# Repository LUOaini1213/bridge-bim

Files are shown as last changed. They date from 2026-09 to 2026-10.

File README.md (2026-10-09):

# bridge-bim · 曲线 T 梁桥 BIM



**A curved precast-T-girder highway bridge modelled from its alignment up, in Rhino 8 and IFC 4.3, with a
construction-stage structural analysis written back into the model.**
A 1110 m route (tangent – clothoid – circular arc – clothoid – tangent, with a parabolic crest curve and
superelevation) carries a 12-span, 3-unit continuous bridge: 1470 elements, 120 of them precast T-girders.
Girder lengths are equalised as an interval-stabbing problem — 10 lengths instead of 66, with an optimality
certificate. The superstructure is analysed stage by stage (simply supported girders, then continuity) under
dead load and the JTG D60-2015 lane load, by a standard-library stiffness solver that is cross-checked against
OpenSees. The results size the bearings — for pressure, and for the shear, rotation and slip that temperature,
shrinkage, creep and braking impose on them, which puts PTFE sliding bearings at the expansion ends — and go
back into the Rhino objects and into two IFC structural analysis models. It is a teaching-level analysis — no
prestressing, reinforcement or section-capacity design.
32 design, construction and structural checks all pass, and each is proven to fail on a deliberately
broken model. The precast yard and the erector are scheduled together in 4D and exported with the model
to IFC 4.3 (IfcAlignment + IfcBridge + IfcWorkSchedule + IfcStructuralAnalysisModel), schema-valid and
byte-reproducible. CI re-derives every number in this README from the committed `.3dm`, IFC and CSV files.

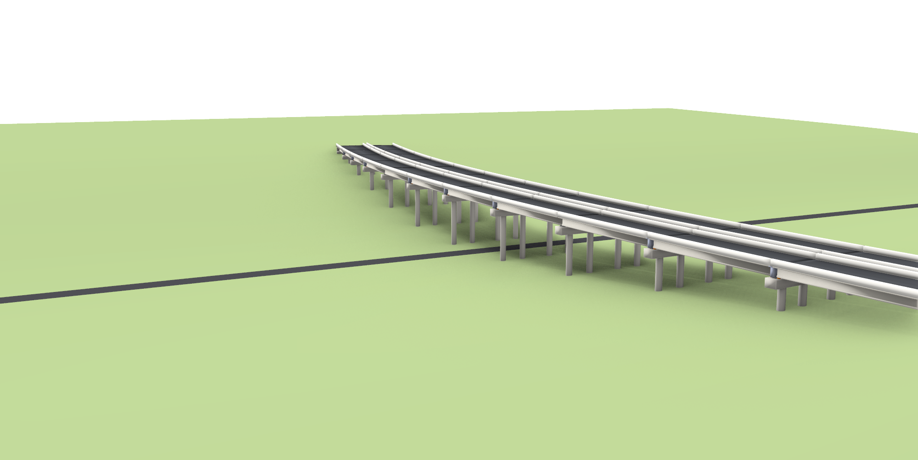
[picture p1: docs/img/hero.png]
Rhino 8 渲染：曲线 T 梁桥与被交道路


## 一眼看懂

- 路线 **1110** m：直线 – 回旋线 – 圆曲线 R=**700** m – 回旋线 – 直线，竖曲线 R=**10000** m，圆曲线段超高 **4%**
- 桥梁 **K10+350.000 – K10+710.000**，**12**×30 m 分 **3** 联、先简支后连续，左右两幅；共 **1470** 个构件，其中预制 T 梁 **120** 片
- 预制梁长：逐片按名义缝宽下料要 **66** 种长度，归并后 **10** 种（中跨 **4** + 边跨 **6**），并给出「不可能更少」的证书
- 上部结构计算：一期恒载由简支的预制梁承担，体系转换后二期恒载与公路-I级车道荷载由连续梁承担；
  30 条梁位线里基本组合正弯矩最大 **10023.1** kN·m、墩顶负弯矩最大 **-6731.5** kN·m，活载长期挠度最大为限值的 **0.238**；
  支座按压应力选平面（伸缩端 φ450、连续墩 500×600），利用率最大 **0.833**；自写求解器与 OpenSees 互核到 1e-9
- 支座位移：伸缩端离一联的不动点最远 **60.62** m，温度、收缩、徐变要缩短 **48.8** mm，普通板式支座最厚一档也不够，
  改用四氟滑板支座；连续墩的普通板式支座剪切变形利用率 **0.822**。横向分布按教材更严的窄桥判别 θ' = **0.408** > 0.3，
  另用 G-M 法算一遍取大值
- 检查：模型 17 条 + 梁场与架梁 5 条 + 上部结构 10 条，**32/32** 通过；每条都有一个故意弄坏的反例，证明它会变红
- 4D 原基线：梁场 **16** 个台座提前 **21** 天开工，架桥机 **50** 天架完 120 片、**0** 天等梁；存梁峰值 **34** 片（容量 **40**）；**2027-02-02** 完成全部体系转换。新增完整示例计划含后续工序，默认转换与收尾日期见下文
- IFC 4.3：**111,481** 个实体，schema 校验 **0** 个问题；几何引擎逐件算出实体，体积与位置和模型一致到 1e-6
- 下文每个数字都由 `scripts/check_readme.py` 对着已提交的产物回算，CI 每次提交都跑

路线、地形、桥梁都是虚构的示例；尺寸、工效、设备能力这些不是物理常数的参数集中在
[`bridge/config.py`](bridge/config.py)，逐项标着【几何】或【假设】。改那里、重跑，下面的表全部跟着变。

## 一个模型，多份产物

```mermaid
flowchart LR
  cfg["bridge/config.py<br/>路线 · 桥型 · 工效参数 · 规范系数"] --> core["bridge/<br/>路线 · 构件 · 检查 · 梁长归并 · 排程 · 结构计算"]
  core --> rh["Rhino 8<br/>rhino/build_model.py"]
  rh --> m3["model/bridge_bim.3dm<br/>构件 + BIM 属性 + 内力"]
  rh --> img["docs/img/*.png<br/>渲染 · 4D · 图纸 · 弯矩包络"]
  core --> ifc["model/bridge_bim.ifc<br/>IFC 4.3 + 结构分析模型"]
  core --> csv["data/*.csv<br/>梁长 · 垫石标高 · 工程量 · 排程 · 内力 · 支座反力"]
  m3 -. rhino3dm 读回 .-> ci["tests/ + CI"]
  ifc -. ifcopenshell 读回 + 几何引擎 .-> ci
  csv -. 重算比对 .-> ci
```

构件几何只算一次（[`bridge/model.py`](bridge/model.py)），Rhino 脚本和 IFC 导出读的是同一份顶点与参数；
`.3dm` 由 rhino3dm 读回、IFC 由 ifcopenshell 的几何引擎重新算成实体，各自和模型逐件对照。
IFC 不从 `.3dm` 反读，因为路线的语义定义（线元类型、半径、回旋线参数、竖曲线）在 Rhino 的网格里已经不存在了。

## 路线：平、纵、横

| 线元 | 起点桩号 | 长度 (m) | 曲率 |
|---|---|---|---|
| 直线 | K10+000.000 | 320 | 0 |
| 回旋线 | K10+320.000 | 110 | 0 → 1/700 |
| 圆曲线 | K10+430.000 | 190 | 1/700 |
| 回旋线 | K10+620.000 | 110 | 1/700 → 0 |
| 直线 | K10+730.000 | 380 | 0 |

回旋线没有解析解：平面坐标用分段 5 点 Gauss–Legendre 积分方位角得到，再拿测量上的级数公式
（x = l − l⁵/40A⁴ + …，y = l³/6A² − …）独立算一遍，两者差 < 1e-9 m；导出的 IfcGradientCurve 交给
ifcopenshell 的几何内核求值，是第三种算法，与自己的积分在平面上差 < 1e-5 m、高程上差 < 1e-6 m。

纵断面：变坡点 K10+520.000，高程 136.320，前坡 +1.600%、后坡 -1.200%，抛物线竖曲线 L=280 m
（R=10000，T=140，E=0.980）。横坡：直线段各幅 2% 向外侧排水，圆曲线段两幅都 4% 超高向曲线内侧，
在回旋线上线性过渡；每幅绕自己的中心线旋转。

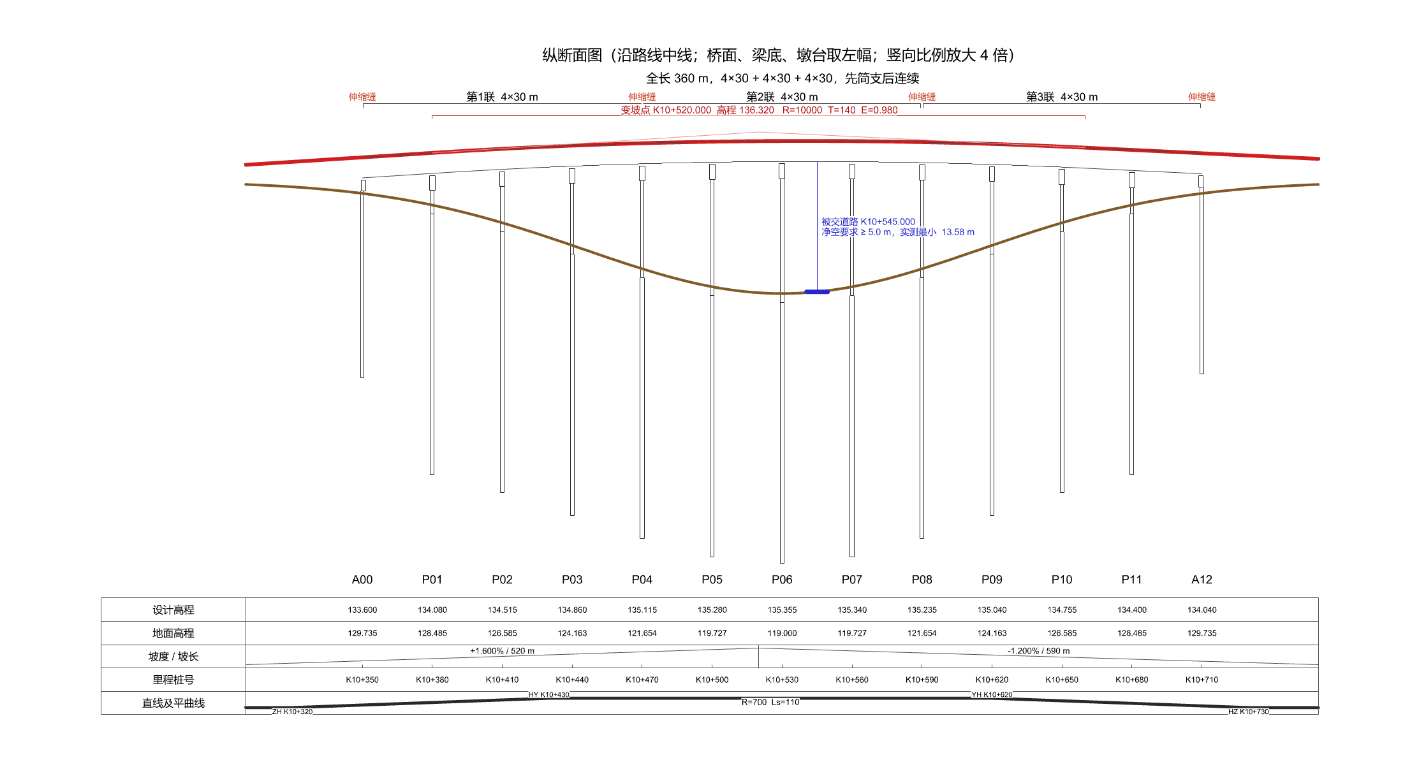
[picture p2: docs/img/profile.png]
纵断面图：地面线、设计线、墩台、竖曲线要素与资料表


## 结构体系：先简支后连续

12 跨分 3 联（4×30 + 4×30 + 4×30）。13 条支承线分三种：2 个桥台、2 个过渡墩（两联交界，设伸缩缝）、
9 个连续墩。

- **伸缩端**（桥台、过渡墩）：梁端面距支承线 0.04 m，联与联之间留 0.08 m 伸缩缝；梁直接落在四氟滑板支座 GYZF4 φ450×87 上，共 60 个。
- **连续端**（连续墩）：架梁时两跨梁端各落在一个临时支座上，共 180 个；墩中心一排 GJZ 500×600×90 矩形板式支座（90 个，
  顺桥向 500 mm）整个落在两梁端之间的缝下，体系转换前不接触预制梁。浇墩顶现浇连续段、张拉负弯矩钢束后拆临时支座，
  由永久支座受力。连续段宽 0.708–0.998 m，由梁长归并决定（见下节）。支座规格由压应力、剪切变形、转角与抗滑验算定
  （见「上部结构计算」）。
- 梁端面平行于径向支承线（曲线上最大斜角 1.228°），所以同一条缝在梁宽范围内等宽；
  盖梁、台帽顶面按该处桥面横坡做成斜面，垫石高 0.150–0.156 m。
- 每跨相邻两片梁之间 5 道横隔板（两道端横隔板 + 1/4、1/2、3/4 跨），沿径向、腹板面到腹板面：
  这是荷载横向分布用修正偏心压力法的前提（桥上有可靠的横向联结）。

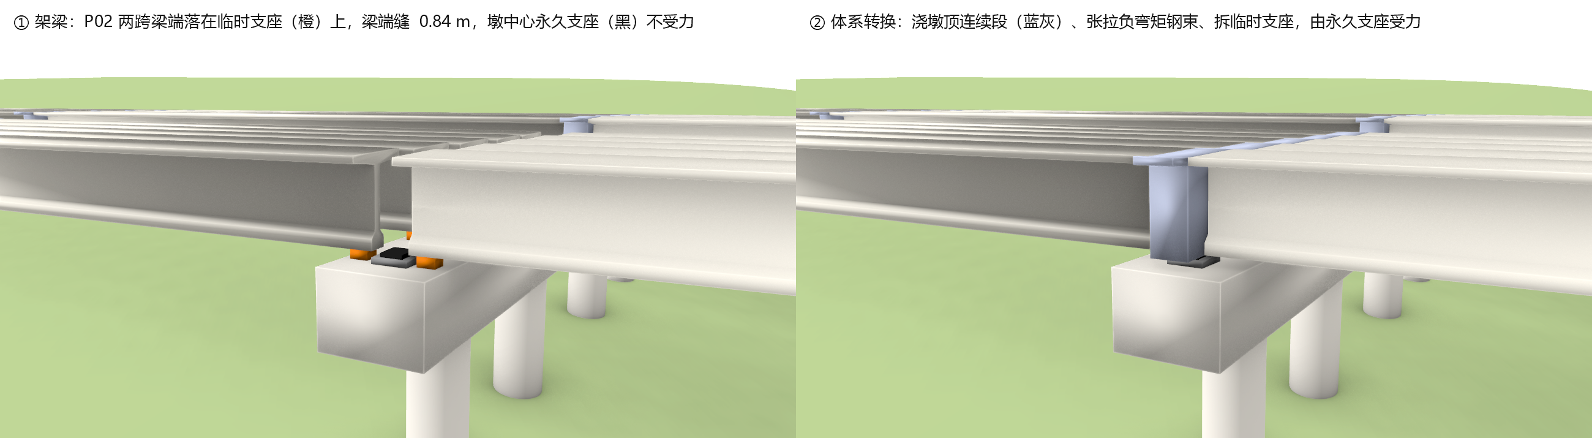
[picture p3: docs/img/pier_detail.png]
连续墩近景：① 架梁阶段落在临时支座上 ② 体系转换后由永久支座受力


## 梁长归并：66 种 → 10 种

直梁放在曲线上：每片梁搁在两条径向支承线之间、同一偏距处两点连成的三维弦上，曲线外侧的弦比内侧长，
左右两幅、每跨、每个梁位都不一样。逐片按名义缝宽（伸缩端 0.04 m、连续端 0.425 m）下料取整到 10 mm，
要 **66** 种梁长——66 种端模设置。

但连续端的缝宽可以在 0.35–0.50 m 之间浮动（连续段宽 0.70–1.00 m），伸缩端不动。于是每片梁的可行长度是
一个区间，问题变成「用最少的长度刺穿全部区间」。这是区间刺穿：按右端点排序，遇到还没被刺穿的区间就在它的
右端点放一个点——贪心的结果可证最优。程序同时输出**证书**：一组两两不相交的区间，个数等于所选长度数，
任何方案都至少要这么多种。中跨梁（两端连续）与边跨梁（一端伸缩）的端部构造不同，分开归并：

| 梁型 | 长度 (m) | 片数 |
|---|---|---|
| 中跨 | 28.78 | 16 |
| 中跨 | 29.09 | 20 |
| 中跨 | 29.41 | 20 |
| 中跨 | 29.74 | 4 |
| 边跨 | 29.09 | 8 |
| 边跨 | 29.30 | 11 |
| 边跨 | 29.48 | 11 |
| 边跨 | 29.63 | 13 |
| 边跨 | 29.80 | 9 |
| 边跨 | 30.01 | 8 |

允许的缝宽浮动越大，需要的长度越少——这是现浇工作量与预制规格之间的取舍：

| 连续端浮动 | 连续段宽 (m) | 中跨 | 边跨 | 合计 |
|---|---|---|---|---|
| ±0.005 | 0.84–0.86 | 34 | 26 | 60 |
| ±0.020 | 0.81–0.89 | 10 | 16 | 26 |
| ±0.040 | 0.77–0.93 | 6 | 11 | 17 |
| ±0.060 | 0.73–0.97 | 4 | 7 | 11 |
| ±0.075 | 0.70–1.00 | 4 | 6 | 10 |
| ±0.100 | 0.65–1.05 | 3 | 5 | 8 |
| ±0.125 | 0.60–1.10 | 2 | 4 | 6 |
| ±0.150 | 0.55–1.15 | 2 | 4 | 6 |

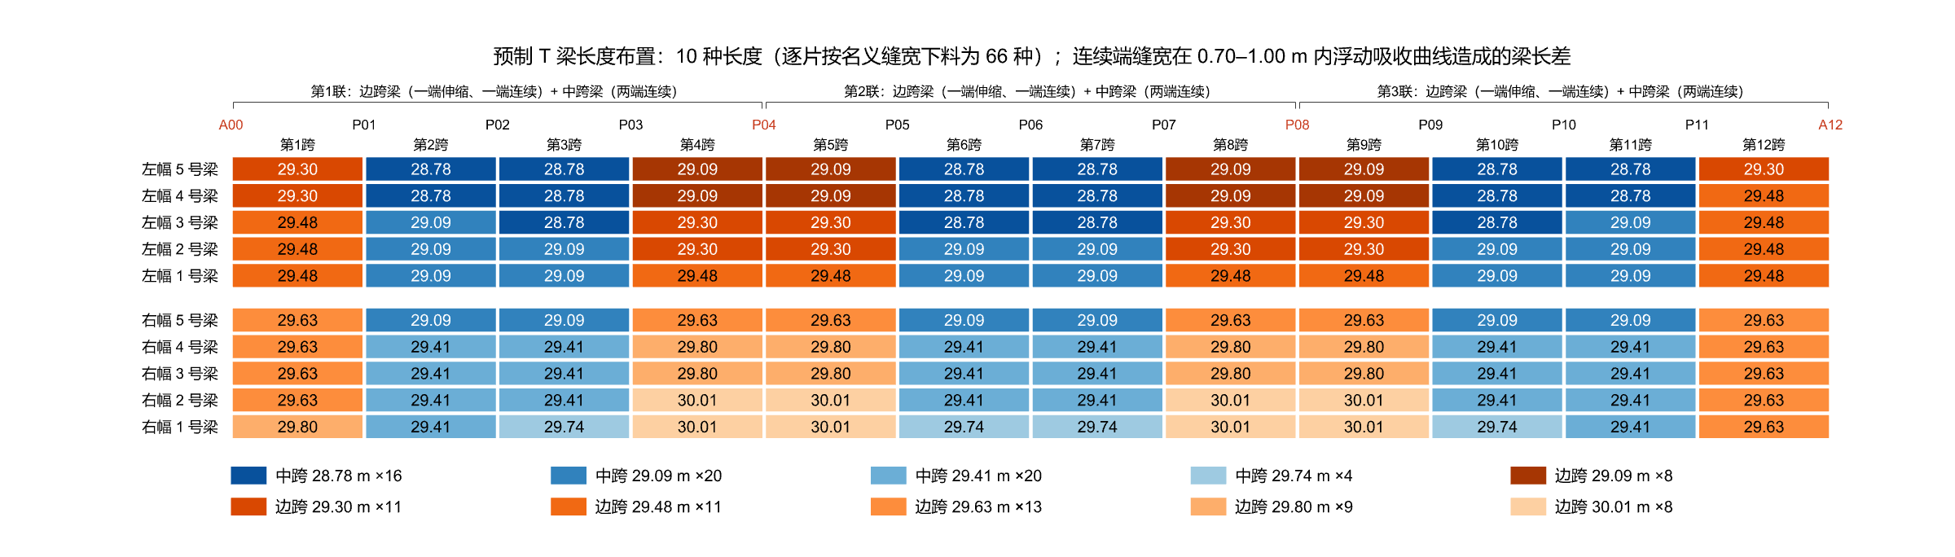
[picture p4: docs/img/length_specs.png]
预制 T 梁长度布置：10 种长度


## 构件与检查

| 类别 | 数量 |
|---|---|
| 预制 T 梁 | 120 |
| 横隔板 | 480 |
| 湿接缝 | 96 |
| 翼缘现浇段 | 48 |
| 墩顶现浇连续段 | 18 |
| 桥面铺装 | 24 |
| 混凝土护栏 | 48 |
| 伸缩装置 | 8 |
| 支座垫石 | 150 |
| 板式橡胶支座 | 150 |
| 临时支座 | 180 |
| 盖梁 | 22 |
| 桥台台帽 | 4 |
| 桥台背墙 | 4 |
| 墩柱 | 44 |
| 系梁 | 22 |
| 钻孔灌注桩 | 52 |

铺装、护栏、翼缘现浇段沿路线每 1.5 m 取样，外缘跟随曲线（直梁「以直代曲」，曲线由现浇部分吸收）；
每个多面体都闭合、法向朝外，共 1382 个实体。检查直接在生成出的几何上量，不信任「按构造应当成立」：

| 检查 | 结果 | 实测 |
|---|---|---|
| 平曲线线元衔接：位置、方位角、曲率连续 | ✅ | 4 处衔接，最大位置差 < 1e-09 m，方位角差 < 1e-09 rad，曲率差 < 1e-12 |
| 竖曲线起终点：高程与纵坡连续 | ✅ | 2 处，最大高程差 < 1e-09 m，坡度差 < 1e-09 |
| 跨径 = 30 m（沿中线逐跨量） | ✅ | 12 跨，最大偏差 < 1e-09 m |
| 伸缩端梁端距支承线 = 0.04 m（端面与支承线平行） | ✅ | 60 个梁端 × 12 个端面顶点，最大偏差 < 1e-09 m |
| 连续墩现浇连续段宽 0.70 – 1.00 m | ✅ | 90 处，0.708 – 0.998 m，梁端面不平行度 < 1e-09 m |
| 湿接缝宽 ≥ 0.45 m（翼缘边缘实测） | ✅ | 量了 192 处，0.600 – 0.623 m |
| 支座垫石高 0.15 – 0.40 m | ✅ | 150 个垫石，0.150 m（S-L01-5a）– 0.156 m（S-L05-5a） |
| 垫石、临时支座落在盖梁 / 台帽顶面内 | ✅ | 最小边距 0.150 m（TS-R01-2b） |
| 临时支座高 ≥ 0.10 m | ✅ | 180 个，0.226 m（TS-R01-2b）– 0.254 m（TS-R02-1a） |
| 临时支座与永久支座垫石平面净距 ≥ 0.05 m | ✅ | 最小 0.100 m（TS-R10-1a） |
| 连续墩永久支座全在现浇连续段下（距预制梁端 ≥ 0.05 m） | ✅ | 最小 0.100 m（B-P09-R1） |
| 墩盖梁底高出地面（桥台埋入路堤，不在此列） | ✅ | 最小 1.30 m（CAP-P01-L） |
| 被交道路净空 ≥ 5.0 m | ✅ | 最小 13.58 m（G-L07-5 梁底） |
| 墩柱外缘距被交道路边线 ≥ 1.0 m | ✅ | 最小 9.54 m（C-P06-L2） |
| 最重预制梁 ≤ 架桥机额定 120 t | ✅ | G-R08-1 65.2 t，利用率 54% |
| 多面体闭合、法向朝外 | ✅ | 1382 个实体，不合格 0 个 |
| 预制梁长规格数达到下界（区间刺穿最优性证书） | ✅ | 中跨 4 种、边跨 6 种；实际梁长与规格最大差 < 1e-09 m，越出可行区间 0 片 |
| 存梁峰值 ≤ 存梁容量（20 个台座 × 2 层） | ✅ | 容量 40 片，峰值 34 片（2027-01-02） |
| 存梁期 ≤ 90 天 | ✅ | 最长 15 天 |
| 架设时龄期 ≥ 14 天 | ✅ | 最短 18 天 |
| 龙门吊抬吊能力 ≥ 最重预制梁 | ✅ | 2 台 × 50 t × 0.8 = 80 t，最重梁 65.2 t |
| 梁场不占路基（距路线中线 ≥ 25 m） | ✅ | 梁场边缘距中线 38.0 m |

「全过」本身不是证据。[`tests/test_model.py`](tests/test_model.py) 给每条检查配了一个反例：把一片梁的
伸缩端挪 1 cm、把连续端往墩中心线伸 0.2 m、把永久支座往梁端下推 0.1 m、翻转一个面、把一片梁多切 5 cm……
每改一处，对应那一条必须变红。

## 支座垫石标高表

每个永久支座的平面坐标、支座顶、垫石顶、盖梁顶高程与垫石高，全表 150 行见
[`data/bearings.csv`](data/bearings.csv)；临时支座 180 行见 [`data/temp_supports.csv`](data/temp_supports.csv)。节选：

| 支座 | 类型 | 规格 | 墩台 | X | Y | 支座顶 | 垫石顶 | 盖梁顶 | 垫石高 |
|---|---|---|---|---|---|---|---|---|---|
| B-L01-1a | 伸缩端 | GYZF4 φ450×87 | A00 | 302.3540 | 177.0626 | 131.5313 | 131.4443 | 131.2937 | 0.1507 |
| B-L01-2a | 伸缩端 | GYZF4 φ450×87 | A00 | 301.1167 | 179.1772 | 131.4688 | 131.3818 | 131.2313 | 0.1505 |
| B-P01-L1 | 连续墩 | GJZ 500×600×90 | P01 | 327.7582 | 192.2012 | 132.0311 | 131.9411 | 131.7911 | 0.1500 |

## 工程量

| 构件 | 数量 | 混凝土 (m³) | 强度等级 | 钢筋 (t) |
|---|---|---|---|---|
| 预制 T 梁 | 120 | 2943.55 | C50 | 559.27 |
| 横隔板 | 480 | 303.21 | C50 | 45.48 |
| 湿接缝 | 96 | 270.56 | C50 | 48.70 |
| 翼缘现浇段 | 48 | 124.22 | C50 | 22.36 |
| 墩顶现浇连续段 | 18 | 353.65 | C50 | 77.80 |
| 桥面铺装 | 24 | 1690.58 | C40+沥青 | 0.00 |
| 混凝土护栏 | 48 | 935.37 | C30 | 102.89 |
| 支座垫石 | 150 | 13.11 | C50 | 1.31 |
| 盖梁 | 22 | 1030.66 | C40 | 164.90 |
| 桥台台帽 | 4 | 111.26 | C40 | 16.69 |
| 桥台背墙 | 4 | 59.35 | C30 | 7.12 |
| 墩柱 | 44 | 638.32 | C40 | 89.37 |
| 系梁 | 22 | 113.52 | C30 | 13.62 |
| 钻孔灌注桩 | 52 | 3079.14 | C30 | 292.52 |
| 结构混凝土合计（不含铺装） | 1108 | 9975.91 |  | 1442.04 |

混凝土量是每个实体的精确体积（散度定理，对 IFC 几何引擎算出的体积核过）；钢筋按各类构件的
kg/m³ 指标估算【假设】，不是配筋计算的结果。

## 上部结构计算（教学级）

[`bridge/structure.py`](bridge/structure.py) 在同一份构件上算上部结构：截面、荷载、支座位置都从 BIM 构件取，
结果写回 `.3dm` 的构件属性和 IFC 的结构分析模型。只用标准库——平面梁单元直接刚度法、带状 Cholesky 分解、
子空间迭代求频率都是自己写的——所以 Rhino 8 里的 Python 3.9 也能直接跑；测试里再用 OpenSees 逐项互核。
这是教学级的内力估算，不是设计：没有预应力钢束，不验算截面应力与承载力，不计收缩徐变与温度梯度引起的内力
（收缩、徐变与温度只用来算支座位移，见下文）。每个规范系数的出处写在 [`bridge/config.py`](bridge/config.py)，没核到原文的标【假设】。

施工阶段（先简支后连续）：

1. **一期恒载**（预制梁 + 横隔板 + 湿接缝 + 翼缘现浇段，构件体积 × 26 kN/m³）由每片预制梁承担：它两端落在永久支座
   （伸缩端）或临时支座（连续端）上，是简支梁。横隔板作为集中力放在它与梁轴的交点，每道一半给两侧的梁。
2. **体系转换**：浇墩顶连续段（混凝土直接浇在永久支座上【假设】）、拆除临时支座——等于把临时支座在阶段一的反力
   反向加到以永久支座为支承的整联连续梁上。
3. **二期恒载**（铺装 + 护栏，每跨五片梁均分）与**汽车荷载**作用在连续梁上。

全桥一期恒载 94680 kN、二期 65739 kN、连续段 9195 kN；每条梁位线每个阶段的支座反力与荷载平衡，
荷载合计与构件体积 × 容重对账，差都 < 1e-9。

汽车荷载按公路-I级车道荷载：qk = 10.5 kN/m，Pk = 2(L0 + 130) = 318.98–321.01 kN（取该联最大计算跨径【假设】）。
逐节点求影响线，均布荷载布满同号区段、集中荷载放在最大竖标处，剪力与支座反力的 Pk 乘 1.2。
荷载横向分布：跨中用修正偏心压力法，支点用杠杆原理法，1–3 列车逐一枚举并乘横向车道布载系数；弯矩全跨用 mc，
剪力与反力的 m 从支点的 m0 线性过渡到 1/4 跨的 mc。连续梁阶段按教材的「等代简支梁」：按跨中挠度相等求抗弯刚度修正系数
C_w = w简支 / w连续，用本仓的梁单元直接算——两跨等跨 1.391、三跨等跨 1.429 / 1.818，与教材表 2-6-4 一致；本桥最大 1.909
（中跨），以 C_w·I 代入后抗扭修正系数 β 由 0.9310 变为 0.9626（抗扭惯性矩不修正），全桥统一取这个偏安全的值。

窄桥判别：教材同一节还说，连续梁按 θ' = (B/2l)·⁴√(C_w·Jx/Jy) ≤ 0.3 判「窄桥」比 B/l ≤ 0.5 更合适（Jx、Jy 为纵、横向
比拟单宽抗弯惯性矩），不满足时宜用比拟正交异性板法（G-M 法）。Jy 照教材例 2-4-6 的算法取自 BIM 的横隔板：中横隔板厚
0.18 m、底面在梁顶以下 1.60 m、间距 7.5 m，桥面板平均厚 0.198 m，翼板有效宽度按表 2-4-5。本桥 θ' = **0.408**，不算窄桥，
所以两法都算、每片梁取大值。G-M 的横向挠曲方程不查图表，用传递矩阵直接解（与弹性地基梁的 Hetényi 闭式解差 < 1e-10），
K0、K1 按 Kα = K0 + (K1 − K0)√α 内插；影响线是光滑曲线，最不利车位不一定有车轮落在梁位上，用黄金分割找
（与逐毫米扫描差 < 1e-9）。拿它算教材例 2-4-6，三片梁的 mc 与教材差都在 1.1% 以内。结果：边梁、次边梁仍由修正偏心
压力法控制（比 G-M 大 6.8%、1.2%），中梁由 G-M 控制（0.4626 → 0.4870，+5.3%）。

冲击系数按每条梁位线整联连续梁的竖弯频率：正弯矩、剪力与反力用基频 f1 = 3.201–3.459 Hz，μ = 0.1899–0.2036；
负弯矩用该联第一频带的最高一阶（四跨一联取第四阶，约 2.1 f1），μ = 0.3182–0.3310——一阶振型在中间支点处弯矩为零，
高阶振型的最大弯矩就在支点上【假设：按王荣霞等（公路交通科技 2018 年第 5 期，引袁向荣 2013）对三跨连续梁取第三阶
竖弯频率的做法推广】。

对照规范条文说明的估算式：JTG D60-2004 条文说明给连续梁 f1 = 13.616/(2πl²)·√(EIc/mc)（正弯矩、剪力）、
f2 = 23.651/(2πl²)·√(EIc/mc)（负弯矩），同时说基频宜用有限元算，没有更精确的方法时才用估算式（原文没见到，据专利
CN105404718A 的转引）。按每条梁位线的组合截面与跨中每延米质量代入，f1 = 4.417–4.763 Hz、f2 = 7.672–8.273 Hz，比有限元的
基频高 37%–39%、比第四阶高 15%–17%，冲击系数会是 μ = 0.2468–0.2601 与 0.3443–0.3577。差别主要在 f1：等跨连续梁的一阶
振型就是各跨交替的简支振型，有限元的 f1 与一跨简支梁的 π²/(2πl²)·√(EIc/mc) 最多差 0.93%，估算式对等跨的一联偏高。
所以这里照规范「宜用有限元」取有限元频率，估算式只作对照——它给的冲击系数更大。

| 梁位 | 组合截面 I (m⁴) | mc 修正偏心压力法 | mc G-M 法 | mc 采用 | mc（不计抗扭，β = 1） | m0 |
|---|---|---|---|---|---|---|
| 1 / 5 号（边梁） | 0.46662 | 0.8693 | 0.8142 | 0.8693 | 0.8873 | 0.9918 |
| 2 / 4 号 | 0.45330 | 0.6199 | 0.6123 | 0.6199 | 0.6286 | 0.8673 |
| 3 号 | 0.45330 | 0.4626 | 0.4870 | 0.4870 | 0.4626 | 0.8673 |

组合：基本组合 γ0(γG·G + 1.4(1 + μ)Q)，γ0 = 1.1，结构重力有利时 γG 取 1.0；频遇组合 G + 0.7Q。
左幅第 1 联 1 号梁（边梁）按施工阶段拆开的弯矩（kN·m；全表 210 行见 [`data/sections.csv`](data/sections.csv)）：

| 截面 | 阶段一 | 体系转换 | 二期恒载 | 恒载合计 | 汽车 | μ | 基本组合 |
|---|---|---|---|---|---|---|---|
| 第 1 跨正弯矩最大处 | 2711.3 | 4.4 | 1179.0 | 3894.7 | 2462.4 | 0.1972 | 9680.8 |
| P01 墩顶 | 0.0 | -305.6 | -1770.2 | -2075.8 | -1874.1 | 0.3254 | -6565.1 |
| 第 2 跨正弯矩最大处 | 2671.5 | 2.2 | 561.1 | 3234.8 | 2069.5 | 0.1972 | 8085.2 |
| P02 墩顶 | 0.0 | -298.6 | -1189.3 | -1487.9 | -1632.9 | 0.3254 | -5296.7 |

墩顶没有一期恒载弯矩：预制梁在临时支座上简支时，墩顶还没连起来；连续后它只从体系转换里得到一小部分负弯矩，
主要的负弯矩来自二期恒载和汽车荷载。

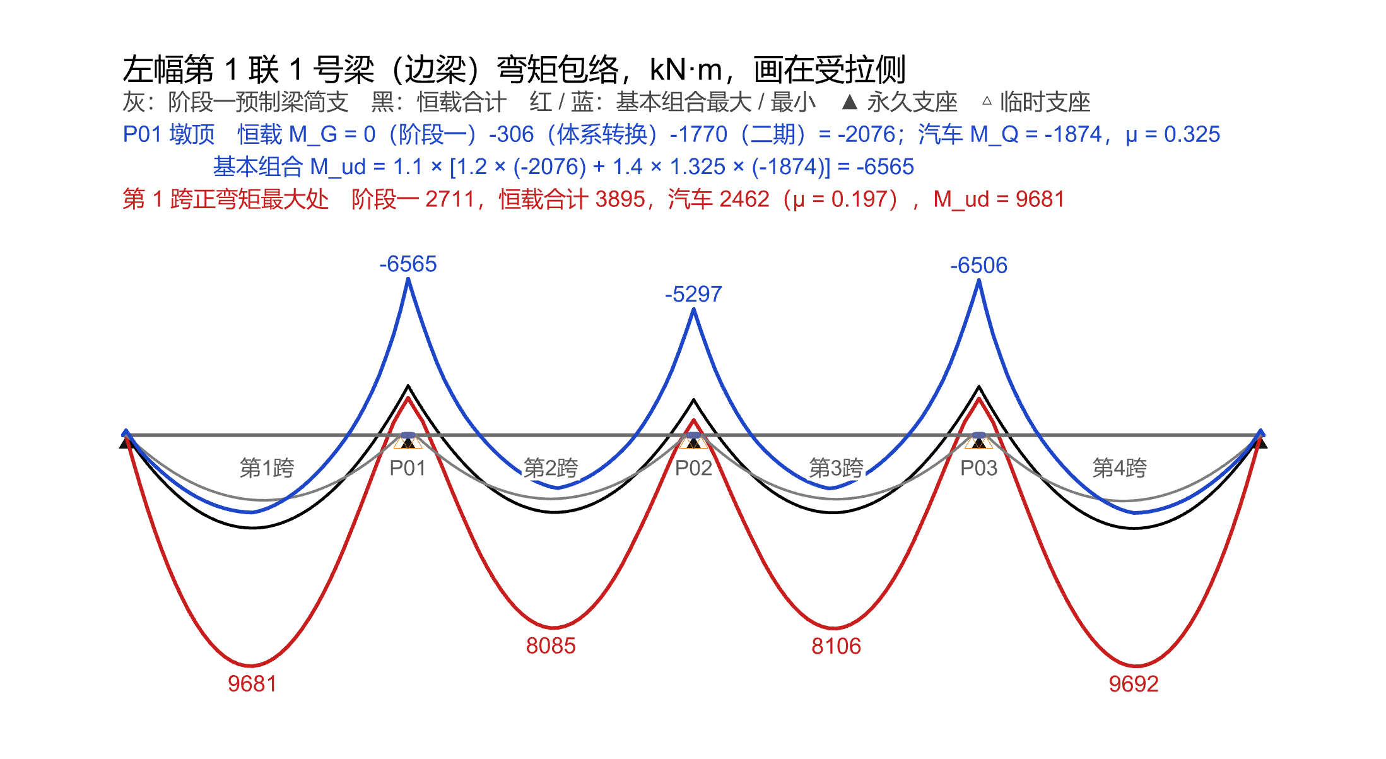
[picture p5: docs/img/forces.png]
弯矩包络：阶段一简支、恒载合计、基本组合最大 / 最小


支座平面：Rck（结构重力与汽车荷载标准值的组合，计冲击）/ Ae（加劲钢板面积）≤ σc。伸缩端 Rck 最大 1244.8 kN、
需要直径 0.408 m，取 φ450；连续墩 Rck 最大 2408.9 kN，圆形要 φ564，按 50 mm 进级是 φ600——可连续端梁端离墩中心线
最近只有 0.35 m，φ600 的边缘离梁端只剩 0.05 m，正好卡在检查下限上。所以用矩形 500 × 600（顺桥向 × 横桥向），
顺桥向离梁端 0.100 m。σc = 10 MPa：JTG 3362-2018 第 8.7.3 条规定 Ae ≥ Rck/σc、σc 按 JT/T 4 取用；JT/T 4 原文没核到，
但厂家按 JT/T 4 列的规格表里 GYZ d450、GJZ 500×600 的最大承压力 1521 kN、2891 kN，正好是 10 MPa × 加劲钢板面积
（每边扣 5 mm 保护层）。型号沿用这张表的 JT/T 4-2004 写法，2019 版改称 GBZY、GBZJ，滑板式为 GBZYH。

**支座位移与剪切变形**（JTG 3362-2018 第 8.7.3–8.7.5 条；位移按第 8.8.2 条伸缩量的算法）：

- **不动点**：每幅每联按普通板式支座的抗推刚度 Ge·Ag/te 求平面形心；滑板支座不计，墩台按刚性（柔性墩会分走
  一部分位移，对支座偏安全）。支座各向同性，温度与收缩徐变让整联绕这一点等比例伸缩——每个支座的位移 = 它到不动点的
  平面距离 × 应变，曲线桥上方向自动沿弦线。
- **温度**：温热地区【假设：路线虚构，与 11 月至次年 2 月照常施工的计划相符】，混凝土桥有效温度 34 / -3 ℃
  （JTG D60-2015 表 4.3.12-2），支座开始受力时的结构温度 10–20 ℃【假设】，线膨胀系数 1.0e-05。
- **收缩与徐变**：附录 C 的公式（用它回算表 C.1.2、C.2.2 核过），RH 80%【假设】，理论厚度 h = 2A/u = 210.1 mm，从 7 d
  开始收缩，取终极值。支座开始受力的龄期取自梁场与架梁计划：伸缩端是落梁时，最年轻 18 d；连续墩是浇墩顶连续段那天，
  19 d——全联都按最年轻的一片算。徐变要截面重心的预压应力 σpc，而这里没有钢束设计：按全预应力构件的抗裂条件
  （第 6.3.1 条，频遇组合下跨中下缘 σst − 0.85σpc ≤ 0，钢束重心距梁底 0.15 m【假设】）反推每片梁要的有效预加力，
  最大 4455 kN、σpc = 5.33 MPa（各片 3.64–5.33 MPa），全桥统一取最大值。
- **制动力**：一联 120 m 上 10% × (qk·L + Pk) 不到 165 kN，取 165 kN；三车道同向 × 2.34 = 386.1 kN，全部由连续墩的
  普通板式支座按刚度分担，整联平移 5.1 mm。

最不利的两个支座（全表 150 行见 [`data/bearing_design.csv`](data/bearing_design.csv)）：

| 支座 | 规格 | 到不动点 (m) | 龄期 (d) | 温度 / 收缩 / 徐变应变 (×10⁻⁶) | 缩短 (mm) | 伸长 (mm) | 制动 (mm) |
|---|---|---|---|---|---|---|---|
| B-R09-1a | GYZF4 φ450×87 | 60.545 | 18 | 230.0 / 284.1 / 291.3 | 48.8 | 14.5 | 0.0 |
| B-P09-R1 | GJZ 500×600×90 | 30.765 | 19 | 230.0 / 282.9 / 288.3 | 24.7 | 7.4 | 5.1 |

伸缩端要缩短 48.8 mm：GYZ d450 最厚一档（总厚 114 mm、橡胶层 82 mm）容许 (te − 5)/2 = 38.5 mm，不够。所以伸缩端用
四氟滑板支座 GYZF4：橡胶部分同 GYZ d450×84，面贴 3 mm 聚四氟乙烯板，梁底配不锈钢板，温度、收缩徐变的位移由滑动吸收
（厂家的产品说明也把多跨连续梁桥列为它作活动支座的用途）。连续墩离不动点最远 30.9 m，GJZ 500×600×90（橡胶层 65 mm）
容许 30.0 mm，剪切变形利用率 0.822。容许值照厂家表的算法扣掉上下各 2.5 mm 保护层——表里的 Δl1 = (te − 5)/2、
Δl2 = 0.7(te − 5)，两个规格八档都对上。

这些输入里假设最多的是气候、湿度与 σpc。每次只改一项（[`data/bearing_sensitivity.csv`](data/bearing_sensitivity.csv)）：

| 变化 | 伸缩端缩短 (mm) | 普通板式 GYZ d450 要多厚 (mm) | 连续墩缩短 (mm) | GJZ 500×600×90 利用率 | GJZ 要多厚 (mm) |
|---|---|---|---|---|---|
| 本桥：温热地区、RH 80%、σpc 取反推值、收缩徐变取终极值 | 48.8 | 不够 | 24.7 | 0.82 | 90 |
| 寒冷地区（Tmin −10 ℃，Ge 1.2 MPa） | 53.0 | 不够 | 26.8 | 0.89 | 90 |
| 严寒地区（Tmin −23 ℃，Ge 1.5 MPa） | 60.9 | 不够 | 30.8 | 1.03 | 110 |
| RH 40%–70%（按 55%） | 66.5 | 不够 | 33.6 | 1.12 | 110 |
| 不计徐变（σpc = 0） | 31.1 | 99 | 15.8 | 0.53 | 70 |
| 收缩徐变只算到 10 年 | 44.8 | 不够 | 22.6 | 0.75 | 90 |
| 安装温度放宽到 5–25 ℃ | 51.8 | 不够 | 26.2 | 0.87 | 90 |

伸缩端用滑板支座这个结论，只在不计徐变时才不成立；连续墩的 90 mm 一档，在严寒地区或 RH 55% 的干燥地区要换 110 mm。

其余几条（转角、压缩、加劲钢板、抗滑、四氟滑板摩擦、滑板行程与梁端缝）见下表。转角是一期恒载（预制梁简支时）、
体系转换与二期恒载、汽车荷载（计冲击）在支座顶面引起的转角之和，不计预应力反拱——它与自重转角方向相反，但没有钢束
设计算不出净值。支座都水平安放：纵坡最大 1.6%，超过第 8.7.3 条允许直接放在梁底斜面下的 1%，梁底要设调平楔块
（模型里没有单独建）。

| 检查 | 结果 | 实测 |
|---|---|---|
| 横向分布方法的前提：宽跨比 ≤ 0.5，每跨每对相邻梁在 1/4、1/2、3/4 跨有横隔板 | ✅ | B/l = 12.75/28.08 = 0.454；96/96 对梁间都有，位置最大偏差 < 1e-06 跨 |
| 连续梁窄桥判别 θ' ≤ 0.3，否则 mc 取 G-M 法包络 | ✅ | θ' = 0.408 > 0.3；修正偏心压力法 / G-M 法：边梁 0.8693 / 0.8142、2 号 0.6199 / 0.6123、中梁 0.4626 / 0.4870，采用两者的大值 |
| 荷载与反力平衡、荷载与构件体积对账 | ✅ | 30 条梁位线 × 3 个阶段，反力与荷载最大相对差 < 1e-09；一期 94680 kN、二期 65739 kN、连续段 9195 kN，与构件体积 × 容重相差 < 1e-09 |
| 汽车荷载长期挠度 ≤ L/600 | ✅ | 最大 12.0 mm / 限值 50.2 mm = 0.24（R 幅第 8 跨 1 号梁） |
| 支座平均压应力 ≤ 10 MPa | ✅ | 150 个永久支座，最大 8.33 MPa = 0.83 σc（B-P05-R1，Rck 2409 kN） |
| 基本组合下支座不脱空 | ✅ | 最小 488 kN（B-L09-5a：恒载 597 kN，汽车最小 -65 kN） |
| 支座剪切变形 te ≥ 2Δl、计制动力 1.43Δl；受压稳定 la/10 ≤ te ≤ la/5 | ✅ | 90 个普通板式支座，最大 Δl 24.7 mm（B-P09-R1，距不动点 30.8 m）≤ 30.0 mm、计制动力 29.8 ≤ 42.0 mm，利用率 0.82；150 个永久支座 te 都在 la/10–la/5 |
| 支座转角 θ·la/2 ≤ δc,m ≤ 0.07te，加劲钢板厚度 | ✅ | 转角最大利用率 0.89（B-R09-1a：θ = 0.00418 rad，含一期恒载、不计反拱；平均压缩 1.06 mm）；平均压缩最大为 0.07te 的 0.34；加劲钢板按式 8.7.3-10 最多要 2.13 mm（B-P05-R1，有 5 mm），最薄 4 mm ≥ 2 mm |
| 支座抗滑与四氟滑板摩擦 | ✅ | 普通板式支座抗滑利用率最大 0.47（B-P07-L5）；60 个滑板支座 μf·R ≤ Ge·Ag·tanα，利用率最大 0.67（B-R09-1a） |
| 伸缩端：滑板行程放得进梁底，升温与制动下梁端缝不闭合 | ✅ | 滑板要伸出 0.279 m ≤ 支座中心到梁端 0.35 m（B-R09-1a）；缝闭合最大 19.6 mm / 缝宽 40 mm = 0.49（EJ-A00-R） |

结构检查同样先证明会失败：[`tests/test_structure.py`](tests/test_structure.py) 给每条配了反例——把一道横隔板挪 3 m、
漏算每跨一道横隔板、连续段混凝土算两遍、把挠度刚度 0.95EcI 改成 0.05EcI、在 BIM 里把一个支座顺桥向改成 300 mm、
把容重改成 0.3 kN/m³ 让桥面「失重」——对应那一条必须变红。新加的几条也一样：关掉 G-M 包络；伸缩端换回普通板式支座、
连续墩支座换成 70 mm 一档、伸缩端橡胶换成最薄的 69 mm 一档；摩擦系数改成 0.1、四氟板不加硅脂（0.12）；在 BIM 里把
一道伸缩缝改成 15 mm、支座离梁端只剩 0.26 m。求解器本身先对闭式解（简支、外伸、两跨与四跨等跨
连续梁的弯矩与反力，简支梁与两跨连续梁的频率）、教材的等代简支梁刚度修正系数表和文献的三跨频率比，再在 OpenSees
里把同一条梁位线建一遍（elasticBeamColumn、beamUniform / beamPoint 荷载、一致质量），节点位移、弯矩、反力、
影响线竖标与前四阶频率逐项差 < 1e-9（相对）；[`scripts/mutation_drill.py`](scripts/mutation_drill.py)
对求解器做 13 种变异（刚度矩阵一个元素 ×1.001、一致质量系数写错、单元内集中力的固端力左右对调、漏掉集中力 Pk、
负弯矩冲击系数取第二阶频率、G-M 找车位只粗扫不细化、徐变系数的指数写错、支座橡胶层没扣保护层……），每种都有测试失败。新写的几块同样先对外部答案：G-M 解对弹性地基梁的闭式解、
全宽平均为 1、互等定理、θ → 0 的刚性极限与教材例 2-4-6；收缩徐变公式回算附录 C 的两张表；规格表的橡胶层、钢板与
容许位移逐档自洽；支座转角影响线对互等定理与简支梁端转角 qL³/24EI。

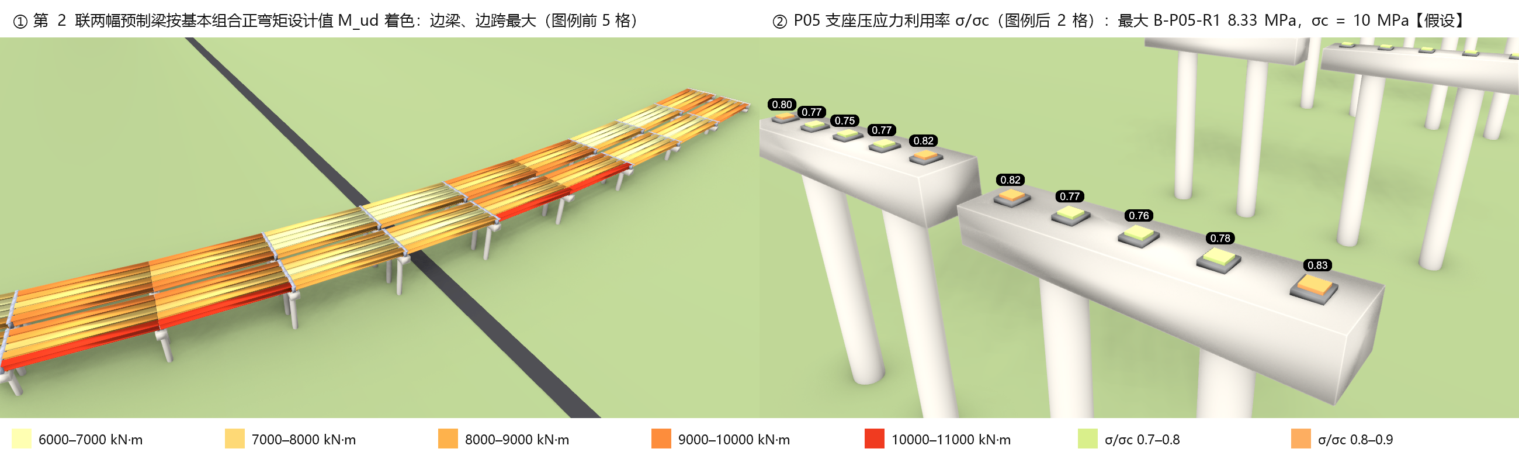
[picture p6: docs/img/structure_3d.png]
第 2 联预制梁按弯矩设计值着色；P05 支座按压应力利用率着色


结果回到模型里：120 片预制梁和 330 个支座（永久 150 + 临时 180）在 `.3dm` 的 UserText 与 IFC 的属性集
BridgeBIM_Structural 里带着内力设计值、挠度、反力与压应力，永久支座还带着到不动点的距离、缩短与伸长量、转角和各条
验算的利用率；逐片、逐个的数在 [`data/girder_forces.csv`](data/girder_forces.csv)、
[`data/bearing_reactions.csv`](data/bearing_reactions.csv) 与 [`data/bearing_design.csv`](data/bearing_design.csv)。

## 梁场与 4D

梁场设在 0 号桥台前的路基右侧：16 个制梁台座、20 个存梁位 × 2 层、两台 50 t 龙门吊抬吊、钢筋加工区，
运梁便道 58 m 接到 0 号桥台。每个台座 7 天一个周期，开浇满 14 天才能架设；架桥机每天 10 个有效工时，
每片梁 2 小时、每跨架完过孔 6 小时，左幅架完转场 4 天再架右幅。

按这些规则，梁场 **2026-11-16** 开浇，架桥机 **2026-12-07** 开架、**2027-01-25** 架完，历时 **50** 天，
等于「梁全部备齐时」架桥机本身的极限工期 50 天——**0** 天等梁。存梁峰值 **34** 片（**2027-01-02**），
最长存梁 15 天，架设时最短龄期 18 天。

台座数与提前量互相牵制：台座少，架桥机就要停下来等梁；提前开工太多，存梁又放不下。扫一遍
（节选；「可行」= 存梁峰值不超过 40 片、存梁期不超过 90 天）：

| 台座 | 提前 (天) | 架梁 (天) | 等梁 (天) | 存梁峰值 | 最长存梁 (天) | 可行 |
|---|---|---|---|---|---|---|
| 12 | 14 | 70 | 20 | 19 | 11 | 是 |
| 12 | 21 | 63 | 13 | 24 | 14 | 是 |
| 12 | 28 | 56 | 6 | 36 | 21 | 是 |
| 14 | 14 | 60 | 10 | 22 | 11 | 是 |
| 14 | 21 | 53 | 3 | 28 | 14 | 是 |
| 14 | 28 | 50 | 0 | 42 | 21 | 否 |
| 16 | 14 | 53 | 3 | 25 | 11 | 是 |
| 16 | 21 | 50 | 0 | 34 | 15 | 是 |
| 16 | 28 | 50 | 0 | 50 | 22 | 否 |
| 18 | 14 | 50 | 0 | 28 | 11 | 是 |
| 18 | 21 | 50 | 0 | 46 | 18 | 否 |
| 18 | 28 | 50 | 0 | 60 | 25 | 否 |

零等梁又放得下的方案里台座最少的是 **16** 个、提前 **21** 天——就是采用的方案；14 个台座怎么调提前量都做不到
两全。全表在 [`data/sensitivity.csv`](data/sensitivity.csv)。

以下是 `bridge/schedule.py` 保留的原基线（供原图纸、敏感性与支座龄期计算对照）：每幅每联最后一片梁架完的第二天浇墩顶连续段，7 天后张拉负弯矩钢束、拆临时支座。新增完整示例计划按后续工序依赖顺延，IFC 与新 Rhino 时间轴使用新计划：

| 幅 | 联 | 跨 | 连续墩 | 架完 | 浇连续段 | 体系转换 |
|---|---|---|---|---|---|---|
| 左幅 | 第1联 | 1–4 | P01 P02 P03 | 2026-12-13 | 2026-12-14 | 2026-12-21 |
| 左幅 | 第2联 | 5–8 | P05 P06 P07 | 2026-12-21 | 2026-12-22 | 2026-12-29 |
| 左幅 | 第3联 | 9–12 | P09 P10 P11 | 2026-12-29 | 2026-12-30 | 2027-01-06 |
| 右幅 | 第1联 | 1–4 | P01 P02 P03 | 2027-01-09 | 2027-01-10 | 2027-01-17 |
| 右幅 | 第2联 | 5–8 | P05 P06 P07 | 2027-01-17 | 2027-01-18 | 2027-01-25 |
| 右幅 | 第3联 | 9–12 | P09 P10 P11 | 2027-01-25 | 2027-01-26 | 2027-02-02 |

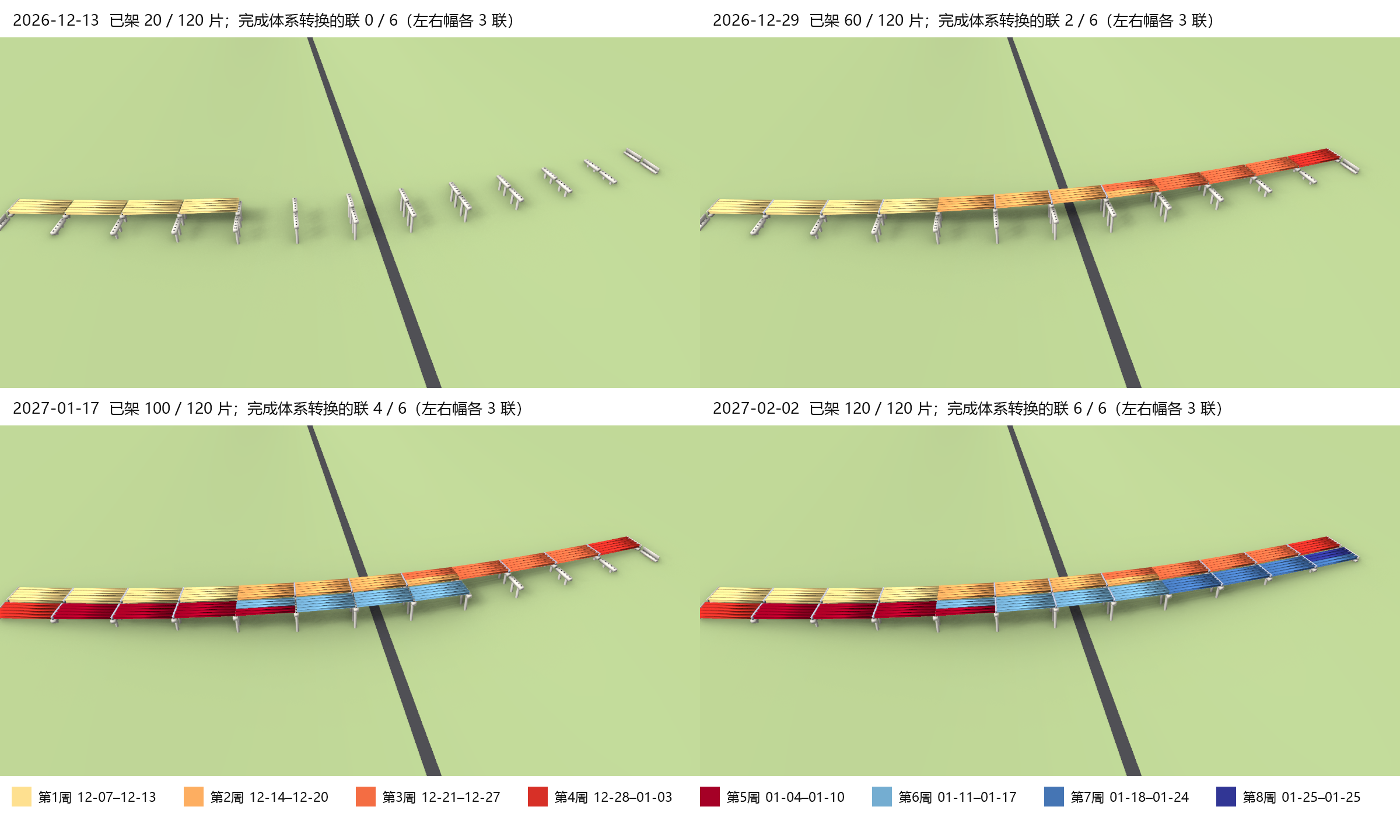
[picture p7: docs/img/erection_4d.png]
4D：四个日期的桥上状态


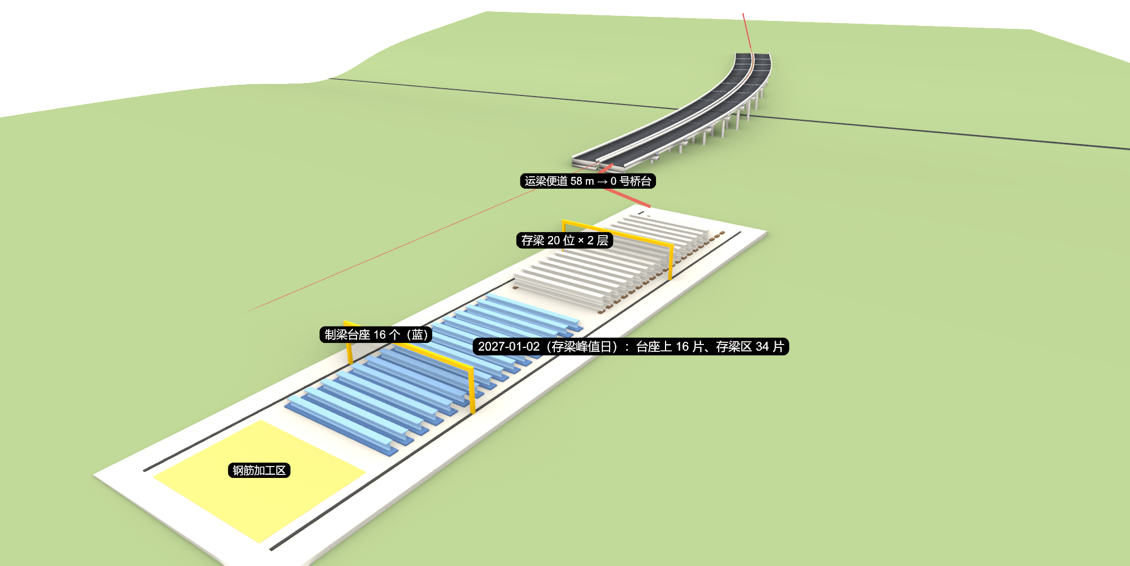
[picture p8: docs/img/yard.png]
存梁峰值日的梁场：台座上在制 16 片、存梁区 34 片


上面原基线图与表不含湿接缝、铺装、护栏；完整示例计划补齐这些工序。

### Rhino 时间轴、完整示例计划与阶段结果

先打开 `model/bridge_bim.3dm`，在 Rhino 8 Python 编辑器运行
[`rhino/replay_construction.py`](rhino/replay_construction.py)，弹出 **Eto 非模态面板**，可继续操作 Rhino。
输入日期/小时/分钟、拖动时间轴、前后跳任务节点，设置每帧推进小时并播放/暂停。
输入 BIM 编号或在视口选中构件再查询，可见其施工、养护、完成时刻及已有阶段结果。
关闭面板会停止计时器；再次运行只保留一个面板。

[`bridge/construction.py`](bridge/construction.py) 是 IFC、Rhino、CSV/JSON 共用的完整示例计划。
默认输入保留原预制、架梁时刻；横隔板 → 湿接缝 → 翼缘现浇（每跨）→ 连续段/养护 → 体系转换（每联）
→ 铺装/养护 → 护栏/养护 → 伸缩装置（相邻两联完成后）有明确完成—开始依赖。
正式输入是 [`construction/input.json`](construction/input.json)，读取和严格校验入口为 [`bridge/construction_input.py`](bridge/construction_input.py)。
`durations` 配置各工种的有效施工小时和连续养护小时；`crews.L/R` 配置每幅每工种的实际班组池，默认均为一组。
班组池覆盖 JSON 中八类后续工种；预制按台座资源排，架设仍使用原单台架桥机顺序，增加班组不会增加架桥机台数。
每个任务记录 `crew_id`，班组在施工结束释放，可在养护期间转到下一跨；多班组确实并行，同一班组不重叠。
`scheduling.crew_strategy` 明确班组派工策略：默认 `fixed_route` 按原跨序及班组尾部可用时间派工，保留默认日期；
`earliest_gap` 按既有预留工作区间寻找可放入当前任务的最早空档，可先做已放行的后跨，再做迟批的前跨。
这两种策略都是满足依赖、门禁、日历和资源的确定性可行排程，不承诺全局最优或任意重排后的最早完工。
旧完整 schema 1 配置仅缺 `scheduling` 时自动补 `fixed_route`，规范配置指纹按补齐后的内容计算；其他缺键、未知键或未知策略仍拒绝。
任务的 `crew_strategy`、`wait_reasons` 和 `effective_wait_reasons` 记录策略及班组/日历/前置放行等待原因；缺验收仍单列 `hold_reasons`。
`calendar` 的 `weekdays` 为周一 0 至周日 6，`rest_dates` 为停工日，`work_dates` 为例外工作日，两列表不允许重叠。
`start_hour` 与 `day_hours` 定义每日班次；开浇、张拉移梁、架设、过孔、后续工序均遵守日历，养护与换幅转场间隔按连续时间计。
台座释放后才允许同台座重用，架设保留不可拆分的过孔作业及换幅转场时间。
默认横隔板、湿接缝、翼缘每跨各施工 4 h、养护 48 h；铺装、护栏每联各施工 20 h、养护 72 h；
伸缩装置每个施工 4 h，转换作业 2 h；连续段施工 10 h、养护 168 h。
`baseline` 可覆写预制/架梁起始日、台座数、台座周期、最小龄期、架设/过孔小时、换幅转场日数和连续段浇筑滞后日数。
施工排程以 JSON 为输入权威；修改 `config.py` 中旧施工常量不会覆写 JSON。几何、荷载与既有整联力学案例仍由 `config.py` 定义。
Python API `compute(configuration=完整字典或JSON路径)` 同源加载；旧 `build(..., assumptions={...})` 保留局部覆盖兼容。
**这些工效、班组与养护停留是演示假设，非现场实测，也不代表混凝土强度验收。**
默认全部体系转换顺延至 **2027-02-09 18:00**，后续收尾至 **2027-02-20 16:00**；
[`data/construction_tasks.csv`](data/construction_tasks.csv) 和 [`data/construction_plan.json`](data/construction_plan.json)
列出每项任务与依赖。`data/conversions.csv` 与 `summary.conversion_last` 是原算法的转换参考：固定原 1 天滞后、7 天养护，不含新增工序和门禁。
这组日期及原支座龄期作对照，不能作为当前 JSON 的最终转换日期；`construction_plan.reference_baseline` 保存该来源说明，完整小时级转换以 `construction_plan` 为准。

`mode=simulation` 将所有任务明确标为演示预测，门禁为 **synthetic release**，没有伪造的验收编号或批准时间。
`mode=project` 不会仅按等待小时放行：预制完成要求 `fabrication_acceptance`；架设还要求 `erection_strength`、`prestress_grout`；混凝土工序完成要求 `concrete_strength`；
转换还要求 `continuity_strength`、`negative_moment_prestress_grout`、`conversion_authorization`，伸缩装置要求 `installation_acceptance`。
每条 `releases` 记录必须含 `task_id/gate/approved_at/reference/source`，缺引用、未知任务/门禁、重复记录、带时区时间都拒绝。
缺批准或前置未放行的任务输出 **HELD** 及原因，批准不能绕过前置依赖。
`start/work_finish/finish` 是排程预测，`effective_*` 与 `release_at` 是满足所选班组策略、输入门禁与其他约束的可行预测，均不是实测进度。
固定路线可能为迟批前跨等待；插空可利用此前的可用区间，但不会绕过门禁或增加架桥机。
迟批会顺延后续工作、过孔及转场，不会在解锁瞬间把下游都算完成；临时支座仅在转换可行预测完成时拆除。
Rhino 的面板、构件查询、UserText、截图和 IFC 任务 Pset 都显示模式、门禁及来源。IFC 仅写 `Schedule*`，不填造假的 `Actual*` 或 `Completion`。
`source` 记录输入文件依据、作者与引用，放行记录应来自项目负责人的强度报告、张拉/压浆记录及转换放行记录；软件不验证签署人的资格或替代现场审批。

修改方法：先复制完整 `construction/input.json` 为自己的 JSON，再修改所需键（以下片段是补丁示意，不能替代完整文件）：

```json
{"crews": {"L": {"diaphragm": 2}},
 "calendar": {"weekdays": [0,1,2,3,4], "rest_dates": ["2026-12-07"], "work_dates": ["2026-12-06"]},
 "durations": {"pavement": {"work_hours": 30, "cure_hours": 96}}}
```

每次重算、IFC 导出、Rhino 回放须用同一输入路径，也可统一设置环境变量 `BRIDGE_CONSTRUCTION_CONFIG`。
保存快照包含完整规范配置和 SHA256，独立读回按快照的配置重建，不会回到默认 simulation。
原 `.3dm` 几何和 `cast/erect` 属性作为源基线保留，配置计划另存 `construction_*`，回放中源梁场峰值几何隐藏。
改变台座布局后要重建完整源模型；仅修改日历、工效、班组或门禁可直接在原源模型回放。

```powershell
python scripts/build_data.py --construction-config construction/my-plan.json
python scripts/export_ifc.py --construction-config construction/my-plan.json
# 仅需更新完整源模型几何（例如台座数变化）时执行下一行：
python scripts/run_rhino.py --construction-config construction/my-plan.json
python scripts/run_rhino.py --jobs rhino/verification_jobs.json --verify-panel --spatial-quality --construction-config construction/my-plan.json
python scripts/build_data.py --check --construction-config construction/my-plan.json
python scripts/export_ifc.py --check --construction-config construction/my-plan.json
python scripts/check_ids.py
python scripts/check_replay.py --all
python scripts/check_project_gates.py
python scripts/check_spatial_quality.py
```

默认输入对应仓库已保存的数值摘要。自定义输入会改变排程和龄期相关结果，随后需更新 README 并运行 `scripts/check_readme.py`，不能沿用默认日期/数量。
[`tests/test_construction_input.py`](tests/test_construction_input.py) 覆盖真实双班组并行、日历、迟批机器链、未批准/已批准及非法输入；
[`tests/test_construction_delivery.py`](tests/test_construction_delivery.py) 核对 IFC 回读门禁、稳定 GUID 与空 Actual 字段。
[`tests/test_crew_strategy.py`](tests/test_crew_strategy.py) 对比迟批前跨/已放行后跨、区间插空、多班组与休息日；
[`tests/test_readme_profile.py`](tests/test_readme_profile.py) 证明施工数字来自选定 JSON，拒绝旧台座数量或篡改的任务表。

仓库 README 是默认输入的参考说明，原转换参考表仍按原算法，不会用自定义 profile 的日期替换整联结构案例。
`python scripts/check_readme.py` 核对全部默认 README 数字，台座数和施工工效读取实际选定配置，默认文字不能冒充自定义配置的结果。
自定义 profile 使用只读 `python scripts/check_readme.py --construction-config construction/my_project.json --profile-summary`：
独立重建并核对当前 `data/construction_plan.json`、全部任务 CSV、预制/架梁表与基线摘要，打印模式、策略、台座数、日历、HELD 数及预测完成时刻。
这项检查不要求重写默认 README 的几何/整联结果与图片；IFC、原生回放和质量检查由交付流程分别核对。
需要核对另存的完整 README/产物时，可传 `--readme`、`--data-dir`、`--ifc`，没有隐式默认输入回退。
源模型的原始 `cast/erect/age` 与既有结构属性属于来源基线，由可移植的 `model/source_config.json` 记录其输入及源文件 SHA。
原生全源构建会更新该记录；当前已独立验证的原源保留原字节，仅初始化来源说明。
`python scripts/check_source.py` 在写入任何新产物前核对真实源 `.3dm` 的单位、唯一构件 ID、来源属性、几何位置/尺寸、闭合网格顶点及面方向、解析圆柱/方盒和台座布局。
新日历、工效、门禁或班组策略直接复用原源，更新的实际配置由回放 `construction_*` 字段记录，原日期仍为参考。
台座数或几何不匹配时明确要求交付流程的 `--regenerate-source`；源与回放相互一致不能替代这项独立几何核验。
[`tests/test_source_profile.py`](tests/test_source_profile.py) 包含平移、单位、篡改属性、同包围盒圆柱换方盒、闭合网格反面及来源指纹反例。
`--verify-panel` 还生成两份带 **测试专用批准** 的原生 project 快照在 `model/project_replay/`，用于证明批准前不可见、批准后仅首梁架设而转换仍阻断。

面板可选择 30 条梁位线及 **M1（一期恒载）/ Mc（体系转换增量）/ M2（二期恒载增量）/ MG（恒载合计）**。
紫色弯矩曲线、带符号反力箭头和有效/无效支承标记生成在“施工阶段结果”层；三维用短标号，截图顶部表格列完整ID及数值。
弯矩图比例自适应，反力箭头长度仅示意，精确值以表格为准。Mc 的临时支座拆除作用单独标注，
不冒充剩余支座反力。数据来自原 `bridge.structure.analyse`，保存在 [`data/stage_results.json`](data/stage_results.json)，
可独立读回核对原生曲线坐标、支座状态与反力。
**这是既有整联载荷工况的查看器；Mc/M2 为增量，日期回放不重新求解部分安装结构。**
原工程结果与原基线支座龄期保持不变；新增示例日历不会自动替换工程分析的施工龄期。
未舍入的阶段 JSON 单独按类型/字段/顺序严格互核。各条 M1/Mc/M2/MG 弯矩曲线沿用 OpenSees 互核的向量门槛：逐点差不超过 `max(2e-9, 1e-9 × max(1, 两份该曲线的最大绝对弯矩))`，覆盖刚度恢复内力时的消去误差；坐标、反力及其他浮点仍按逐值相对门槛 1e-9、绝对下限 2e-9 比对。`build_data.py --check` 输出全部浮点差异的分工况最大绝对误差、门槛比和所有超限位置，供跨平台 CI 核验。
原工程表仍保持原固定小数位的门槛，ID、整数与布尔值没有浮点容差。

也可让本机 Rhino 自动导出指定日期；原完整模型和已发布的结构计算结果不会被覆盖：

```powershell
python scripts/run_rhino.py --replay 2026-12-21
python scripts/check_replay.py model/replay/bridge_2026-12-21.3dm
python scripts/run_rhino.py --replay 2027-02-20T16:00 --stage Mc --line L-U2-G3 --verify-panel
python scripts/check_replay.py model/replay/bridge_2027-02-20_1600_Mc_L-U2-G3.3dm
python scripts/run_rhino.py --dates 2026-12-06 2026-12-21 2027-02-02
python scripts/run_rhino.py --jobs rhino/verification_jobs.json --verify-panel
```

产物位于 `model/replay/`：带日期/时刻/阶段的 `.3dm`、原生视口 PNG 和逐构件状态 JSON；
`--output-dir` 可指定其他目录。独立读回检查核对实际对象显隐、原编号与 BIM 属性、几何包围盒及排程计数。
[`bridge/replay.py`](bridge/replay.py) 的日期状态计算只用标准库，边界测试纳入 CI。

日期单独输入采用日末语义；带时刻输入可区别安装中、施工中、养护、已完成。
完整几何在任务开始时出现，未模拟吊装运动、混凝土体积渐增。临时支座按新转换任务的实际结束时刻拆除。
下部结构、垫石和永久支座为灰色静态参照，不能据此推断它们在该日期已完成。
梁场峰值快照隐藏，当前在制与存梁数按原排程时刻统计。首次生成阶段数据请执行 `python scripts/build_data.py`。

## 图纸

纵断面（上文）按模型的构件与路线函数绘制，附资料表（设计高程、地面高程、坡度坡长、里程桩号、直线及平曲线，
含 ZH / HY / YH / HZ 四个曲线主点）。下面两个横断面不是另画的：Rhino 里用竖直平面剖切模型的网格与 Brep，
截线平移到图纸位置、按构件类别填色。

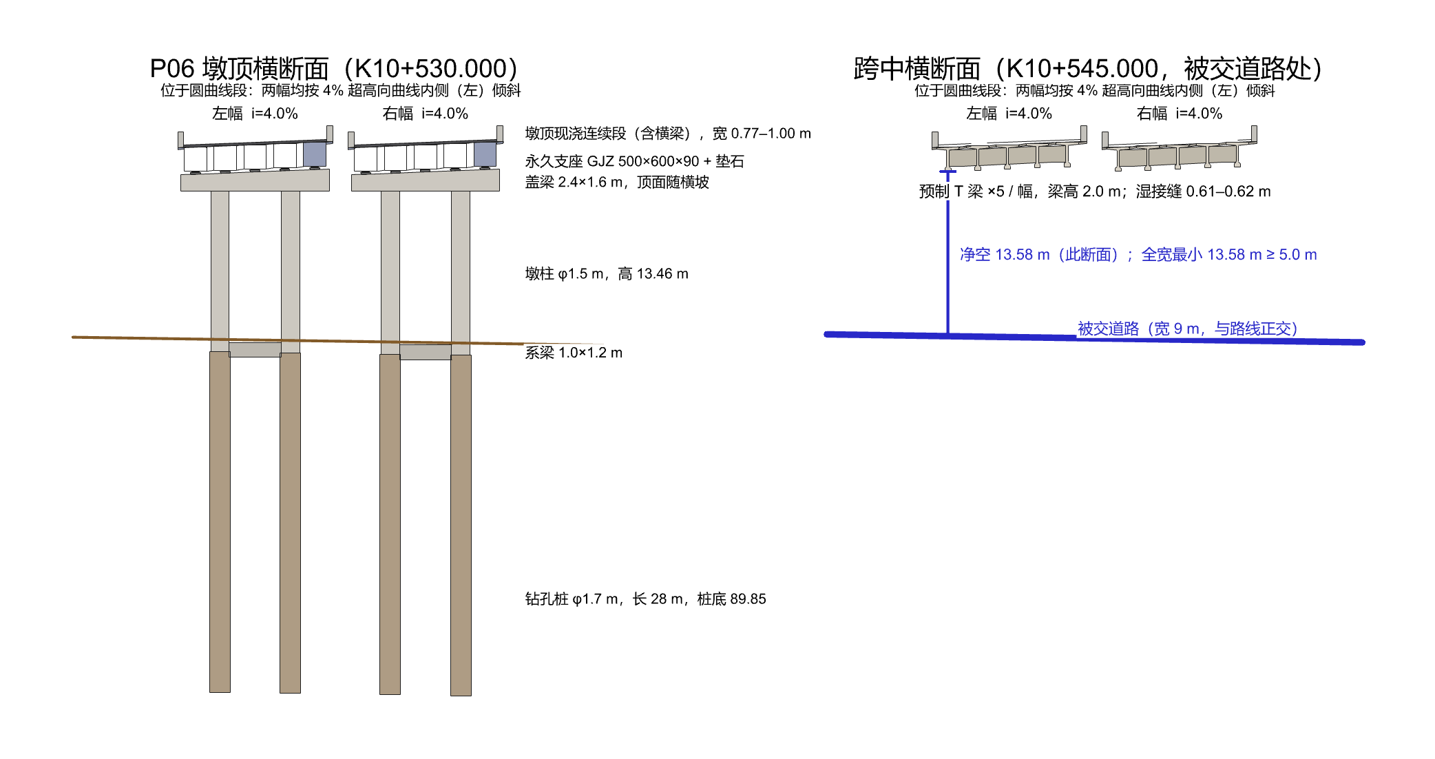
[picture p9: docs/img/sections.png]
P06 墩顶横断面与跨中横断面（被交道路处）


## IFC 4.3

[`model/bridge_bim.ifc`](model/bridge_bim.ifc)（IFC4X3_ADD2）：

- **IfcAlignment**：水平与竖向两层语义定义（线元类型、长度、半径、坡度、竖曲线半径），配 IfcCompositeCurve /
  IfcGradientCurve 几何；13 条支承线各一个 IfcReferent（Pset_Stationing 记桩号）。
- **IfcBridge**（GIRDER）→ 上部结构 / 下部结构 → 左幅、右幅 → 第 1–3 联（DECK_SEGMENT）；桥台与墩（ABUTMENT / PIER）
  用 IfcLinearPlacement 按桩号定位在 IfcGradientCurve 上，共 23 个 IfcBridgePart。
- **预制 T 梁**：IfcBeam T_BEAM，T 形截面（IfcArbitraryClosedProfileDef）沿梁轴斜向拉伸，两端各用一个
  IfcBooleanClippingResult 按径向支承线切齐，共 240 个切割；其余多面体是 IfcPolygonalFaceSet（1262 个，
  与 Rhino 网格同一组顶点），墩柱、桩、支座、系梁是拉伸体。
- **属性与工程量**：每个构件带 BridgeBIM_Element（编号、所属联 / 墩台、梁长、端部类型、缝宽、预制与架设日期、
  支座顶与垫石高程……），标准的 Pset_BeamCommon、Pset_ConcreteElementGeneral、Pset_PrecastConcreteElementGeneral，
  以及按类别的 Qto_*BaseQuantities；标准工程量集里没有体积的类别，体积写进 Qto_BodyGeometryValidation。
- **4D**：IfcWorkPlan → IfcWorkSchedule 下 354 个 IfcTask（预制 120、架设 120、连续段浇筑与体系转换各 6，另有后续工序与汇总任务），
  架设任务以 IfcRelAssignsToProduct 产出对应的梁，体系转换任务以 IfcRelAssignsToProcess 消耗（拆除）临时支座；
  461 条 IfcRelSequence 的时差都按两端任务的实际时刻算出。新增工序产出既有真实构件，
  `BridgeBIM_ConstructionTask` 记录工序类别、模式/预测标记、施工与养护工时、班组与策略/等待原因、规范配置 SHA256、输入来源、门禁记录/原因和可行预测；
  IFC 与 Rhino 使用同一份完整示例计划，原架设/拆除关联保留。
- **结构分析**：两个 IfcStructuralAnalysisModel，按施工阶段分开。阶段一「预制梁简支」：360 根 IfcStructuralCurveMember
  （每片梁两端外伸段 + 支座间）、480 个 IfcStructuralPointConnection，其中 240 个带 IfcBoundaryNodeCondition
  （伸缩端永久支座与临时支座）。阶段二「体系转换后的连续梁」：360 根杆件（每条梁位线 12 段）、390 个节点，
  150 个永久支座为边界条件。荷载工况是一期恒载（DEAD_LOAD_G）、拆除临时支座（PROPPING，反力反向施加）与二期恒载
  （COMPLETION_G1），共 720 条线荷载（按水平投影长度）和 1140 个集中力；结果组是阶段一支座反力与永久支座反力
  标准值组合 Rck，共 390 个 IfcStructuralPointReaction。分析杆件、支承点用 IfcRelAssignsToProduct 挂到对应的梁、
  连续段和支座上。测试核对：杆件端点就是节点、边界条件只在支承处、荷载合计等于计算、反力逐个等于支座表、
  阶段一杆件落在梁轴线上。

| 构件 | IFC 实体 | PredefinedType | 个数 |
|---|---|---|---|
| 预制 T 梁 | IfcBeam | T_BEAM | 120 |
| 横隔板 | IfcBeam | DIAPHRAGM | 480 |
| 盖梁、台帽 | IfcBeam | PIERCAP | 26 |
| 支座垫石 | IfcBeam | HATSTONE | 150 |
| 墩顶连续段、系梁 | IfcBeam | USERDEFINED | 40 |
| 永久支座 | IfcBearing | ELASTOMERIC | 150 |
| 临时支座 | IfcBearing | USERDEFINED | 180 |
| 湿接缝、翼缘现浇段 | IfcSlab | USERDEFINED | 144 |
| 墩柱 | IfcColumn | PIERSTEM | 44 |
| 钻孔灌注桩 | IfcPile | BORED | 52 |
| 桥面铺装 | IfcCourse | PAVEMENT | 24 |
| 混凝土护栏 | IfcRailing | GUARDRAIL | 48 |
| 伸缩装置 | IfcDiscreteAccessory | EXPANSION_JOINT_DEVICE | 8 |
| 桥台背墙 | IfcWall | RETAININGWALL | 4 |

标准资源/日历：16 个 IfcCrewResource、1 个 IfcWorkCalendar，104 个任务通过 IfcRelAssignsToProcess 分配计划班组。
资源分配对应 `Schedule*` 预测，任务的 `EffectiveCrewId` 单独记录门禁后的可行分配，不填实测 `Actual*`。
日历用标准周循环和班次时段表达，停工日为整日 `ExceptionTimes`，例外工作日为限定当天的 `WorkingTimes`；日历控制班组及施工任务，养护仍按连续时间。
班次在午夜结束时 IFC 写合法 `24:00:00`，排程时刻为次日零时；完整周循环不能被额外 `Occurrences` 等隐含限制缩短。
独立只读 `python scripts/check_construction_resources.py` 核对实体数量、班组 ID、任务分配、工时、日历及例外日，亦支持 `--construction-config` 和 `--ifc`。
[`tests/test_construction_resources.py`](tests/test_construction_resources.py) 含 STEP 回读/schema 校验及错误日历、错误分配、伪造实际工时反例。

文件共 **111,481** 个实体，ifcopenshell 的 schema 校验 **0** 个问题。GlobalId 由名称经 uuid5 推出、文件头时间戳固定，
同一份模型每次导出逐字节相同；在另一台机器上重导时，数学库末位的差别只允许落在浮点数的 1e-9（相对）以内，
结构、编号、文字必须逐字相同（[`bridge/numcmp.py`](bridge/numcmp.py)）。交给几何引擎（OpenCascade）逐件算成实体后：
斜拉伸加两次布尔切割的 T 梁与多面体，体积和包围盒都与模型差 < 1e-6；圆柱被引擎离散成多边形，体积差 < 0.5%。

### 原生三维几何校核

`rhino/check_clearance.py` 读取源模型中全部 120 片预制梁的实际闭合网格，保留各平面面片转成 Brep，
把模型的米转换为毫米后检查梁与梁的实体相交体积及可配置净距。默认净距为 25 mm；
支座与设计现浇连接不在此报告范围内，网格见证点不声称为精确最短距离。
源模型不写回；碰撞、净距/接触、几何内核未决分别记录构件编号、Rhino GUID、零件和位置。
两个实际 Brep 都通过轴对齐盒认证时才记录 `actual_gap_mm`，并区分接触、低于阈值及达到阈值；
达到阈值的 `at_clearance` 是边界记录，不计净距不足。比较的数值 epsilon 不代表施工允许偏差。
其他几何的 MeshClash 见证只列为 `threshold_candidate` 待距离复核，不能当成精确最短距离；
认证的箱体距离、原网格见证点及接触搜索结果分别保留，不用包络距离冒充一般实体距离。
空或失败的布尔结果必须有经验证的几何证明才能判无碰撞，否则列为未决。
原生反例覆盖穿透、完全包含、不同高度、阈值、仅接触及包络重叠但位于孔洞中的情况，
另注入失败的交线 API，要求产生未决而非通过。
原六组反例之外，附加同一模型间距在阈值上方、恰好达到阈值及阈值下方的三次边界检查，
并核对小幅低于阈值、非盒网格候选和未认证曲面无网格见证时仍需复核的反例。

```bash
python scripts/run_spatial_quality.py --clearance-mm 25  # 需要 Rhino 8
python scripts/check_spatial_quality.py                 # 无需 Rhino，核对真实源身份/单位并生成 HTML
```

报告在 `model/quality/native_spatial.{json,html}`；信息交付的 IDS 校核由 `scripts/check_ids.py` 单独执行。
实现参考：[Rhino MeshClash](https://mcneel.github.io/rhinocommon-api-docs/api/RhinoCommon/html/M_Rhino_Geometry_Intersect_MeshClash_Search_4.htm)、
[IfcTester / IDS](https://docs.ifcopenshell.org/ifctester.html)。

## 复现

```bash
python -m venv .venv
.venv/Scripts/pip install -r requirements.txt
python scripts/build_data.py              # 重算 data/（只用标准库）
python scripts/export_ifc.py              # 写 model/bridge_bim.ifc
python scripts/run_rhino.py               # 需要本机 Rhino 8：建模、出图、存 .3dm
python -m unittest tests.test_alignment tests.test_model tests.test_schedule tests.test_structure tests.test_replay tests.test_construction tests.test_construction_input tests.test_stage_results
python -m pytest tests                    # 全部测试（含与 OpenSees 互核）
python scripts/check_readme.py            # README 里的数字逐个回算
python scripts/check_ids.py               # quality/delivery.ids + profile.json 信息交付规则，写 model/quality/IDS 报告
python scripts/check_replay.py --all       # 强制八份正式 + 面板导出 QA 产物完整，并独立读回单位/几何/状态/真实阶段结果
python scripts/check_lifecycle.py         # 已保存的原生关闭文档/旧面板隔离/重新打开面板证据
python scripts/tamper_drill.py            # 篡改演练：改一处产物，必须有检查变红
python scripts/mutation_drill.py          # 变异演练：把求解器改错一处，必须有测试失败
```

CI 跑两组：`bridge/` 只用标准库、兼容 Python 3.9（Rhino 8 内置的 CPython 就是 3.9，建模脚本 import 同一份代码），
先单独跑一遍不装任何依赖的测试；再装 ifcopenshell、rhino3dm 与 openseespy 跑全部 258 个测试、重导 IFC 比对、回算 README。
OpenSeesPy 只在测试里用，拿来互核自写的求解器（它的许可对研究、教学与内部使用免费）。
Rhino 那一步在本机跑，它的产物 `model/bridge_bim.3dm` 由 rhino3dm 独立读回来核。

## 仓库结构

| 路径 | 内容 |
|---|---|
| `bridge/config.py` | 全部参数，逐项标【几何】【物理】【假设】 |
| `bridge/alignment.py` | 平曲线积分、回旋线级数、竖曲线、超高、地面线 |
| `bridge/model.py` | 构件生成：分联、梁长归并（区间刺穿 + 证书）、T 梁斜切棱柱、现浇部分、下部结构 |
| `bridge/checks.py` | 17 条模型检查 |
| `bridge/schedule.py` / `bridge/yard.py` | 梁场预制、存梁、架梁、体系转换；梁场布置与 5 条检查 |
| `bridge/construction.py` / `bridge/replay.py` | 完整示例任务、班组/养护依赖与小时级施工状态 |
| `bridge/stage_results.py` / `rhino/stage_viewer.py` / `rhino/timeline_panel.py` | 既有阶段弯矩/反力/支承与非模态 Eto 时间轴 |
| `bridge/structure.py` | 上部结构计算：截面、横向分布（含 G-M 法）、施工阶段、影响线加载、频率与冲击系数、组合、挠度、支座位移与验算；10 条结构检查 |
| `bridge/pipeline.py` | 交付表：梁长、垫石标高、工程量、逐桩坐标、排程、敏感性、内力、支座反力、支座位移 |
| `rhino/build_model.py` | Rhino 8 建模、剖切出横断面、弯矩包络图、按内力着色、出图 |
| `scripts/` | 数据重算、IFC 导出（含结构分析模型）、调起 Rhino、README 回算、篡改演练、变异演练 |
| `tests/` | 路线、模型与反例、排程、结构计算（闭式解、OpenSees 互核、反例）、产物互核、README |
| `data/` | 25 个表（CSV / JSON） |
| `quality/delivery.ids` / `scripts/check_ids.py` | IDS 交付要求与 IFC 信息完整性报告 |
| `model/` | `.3dm`、IFC、Rhino 构建日志 |

## 范围

这是 BIM 建模、施工组织与教学级结构计算的示例，不是桥梁设计：梁高、截面、桩长按公路预制 T 梁桥的常见量级取定值；
结构计算只到内力、挠度与支座，没有预应力钢束、配筋、截面应力与承载力验算，也不计收缩徐变、温度梯度、
预应力次内力与支座沉降引起的内力，内力组合里只有结构重力与汽车荷载；曲线梁的弯扭耦合不计，每条梁位线展开成直梁。
支座位移里：σpc 是按抗裂条件反推的量级，不是钢束设计；转角不计预应力反拱；墩台按刚性，滑板支座的摩擦力不计入
不动点与制动力的分配；湿接缝、连续段这些后浇混凝土更年轻、收缩更大，没有单独算；伸缩装置只核了梁端缝不闭合，
没有按伸缩量选型号。气候、湿度与安装温度是按施工季节取的假设，改一项的结果见上面的敏感性表。
缝宽范围、垫石高度范围等规则是示例取值，不是规范条文。
桥面铺装按「设计路面以下 0.20 m」取底面，预制梁翼缘顶在横坡方向上与它几厘米的高差（由调平层吸收）没有建模。

## 完整交付入口

使用已安装 `requirements.txt` 的虚拟环境 Python。入口会把该解释器传给所有子命令，离线检查不启动 Rhino、不改写正式报告。

```powershell
.\.venv\Scripts\python.exe scripts\delivery.py --check
.\.venv\Scripts\python.exe scripts\delivery.py --rebuild
.\.venv\Scripts\python.exe scripts\delivery.py --rebuild --construction-config construction\my-plan.json
```

`--rebuild` 需要 Windows 和已授权的 Rhino 8，依次刷新数据、IFC/IDS、原生时间轴与空间检查、生命周期和审批反例，再运行独立验收。
默认配置运行全部测试；自定义配置验收实际选定的数据、IFC、原生回放和 profile summary，README 中的默认示例数字保留其参考范围。
日历、工效或审批修改沿用源模型的参考日期；改台座数量或源几何时，明确追加 `--regenerate-source` 重新建源。
常规重建在覆盖任何正式产物前核验实际源模型；独立 `scripts/check_source.py` 核验形状、位置、单位、属性及来源配置。

`model/delivery_index.json` 记录本次通过检查的输入、代码、构造配置、全部交付产物 SHA256 和实际 Python/依赖/Rhino 版本。
文本指纹规范 CRLF 为 LF，二进制模型保持原始 SHA256；改参数、遗漏快照、改源模型或中途失败均不能继续使用旧的通过状态。
无 Rhino 时可运行 `--check` 验收已提交的交付，缺少 Rhino 的重建请求会保留已有产物和索引。

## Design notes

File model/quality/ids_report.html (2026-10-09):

# Bridge BIM IFC delivery requirements

model/bridge_bim.ifc · PASS · 8659 checks, 0 failures

Specification | Requirement | Status | Entities | Failures
Engineering element classification identity and material | Name | PASS | 1470 | 0
Engineering element classification identity and material | BridgeBIM_Element.ElementID | PASS | 1470 | 0
Engineering element classification identity and material | BridgeBIM_Element.Category | PASS | 1470 | 0
Engineering element classification identity and material | BridgeBIM_Element.Deck | PASS | 1470 | 0
Engineering element classification identity and material | Name / Category | PASS | 1470 | 0
Precast girder schedule and structural fields | BridgeBIM_Element.CastDate | PASS | 120 | 0
Precast girder schedule and structural fields | BridgeBIM_Element.ToStorageDate | PASS | 120 | 0
Precast girder schedule and structural fields | BridgeBIM_Element.ErectDate | PASS | 120 | 0
Precast girder schedule and structural fields | BridgeBIM_Structural.MomentFirstStageMax_kNm | PASS | 120 | 0
Precast girder schedule and structural fields | BridgeBIM_Structural.MomentDeadMax_kNm | PASS | 120 | 0
Formal task identification | Name | PASS | 354 | 0
Formal task identification | Identification | PASS | 354 | 0
Named formal work schedule | Name | PASS | 1 | 0

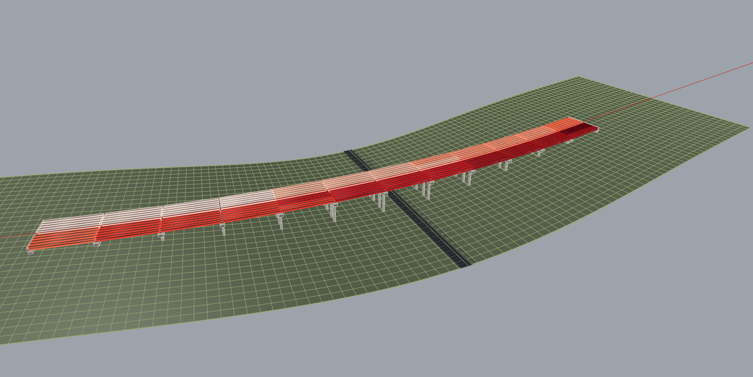
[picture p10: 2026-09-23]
docs/img/erection_weeks.png

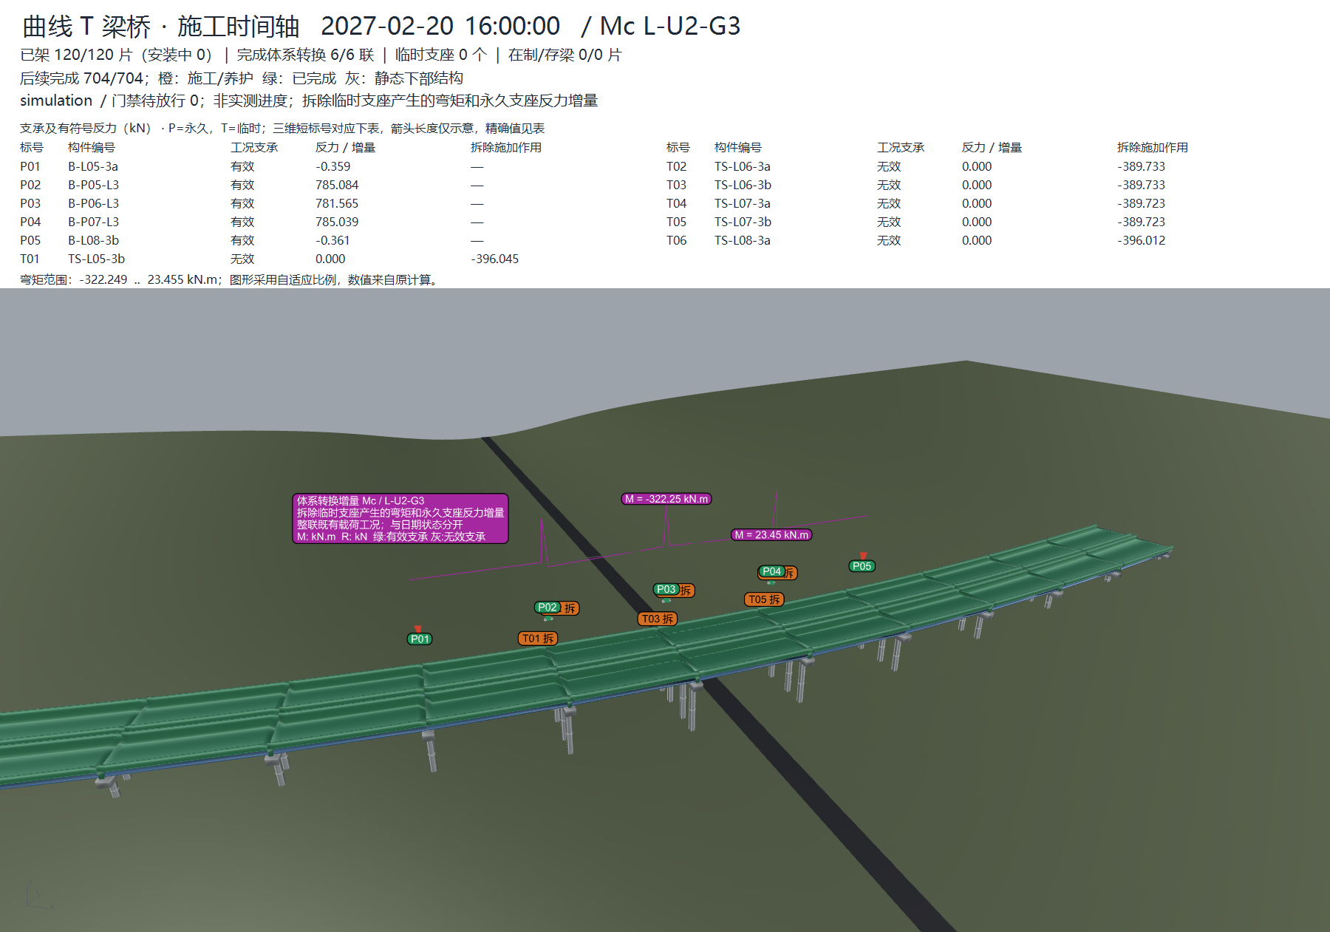
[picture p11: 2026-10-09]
model/replay/bridge_2027-02-20_1600_Mc_L-U2-G3.png

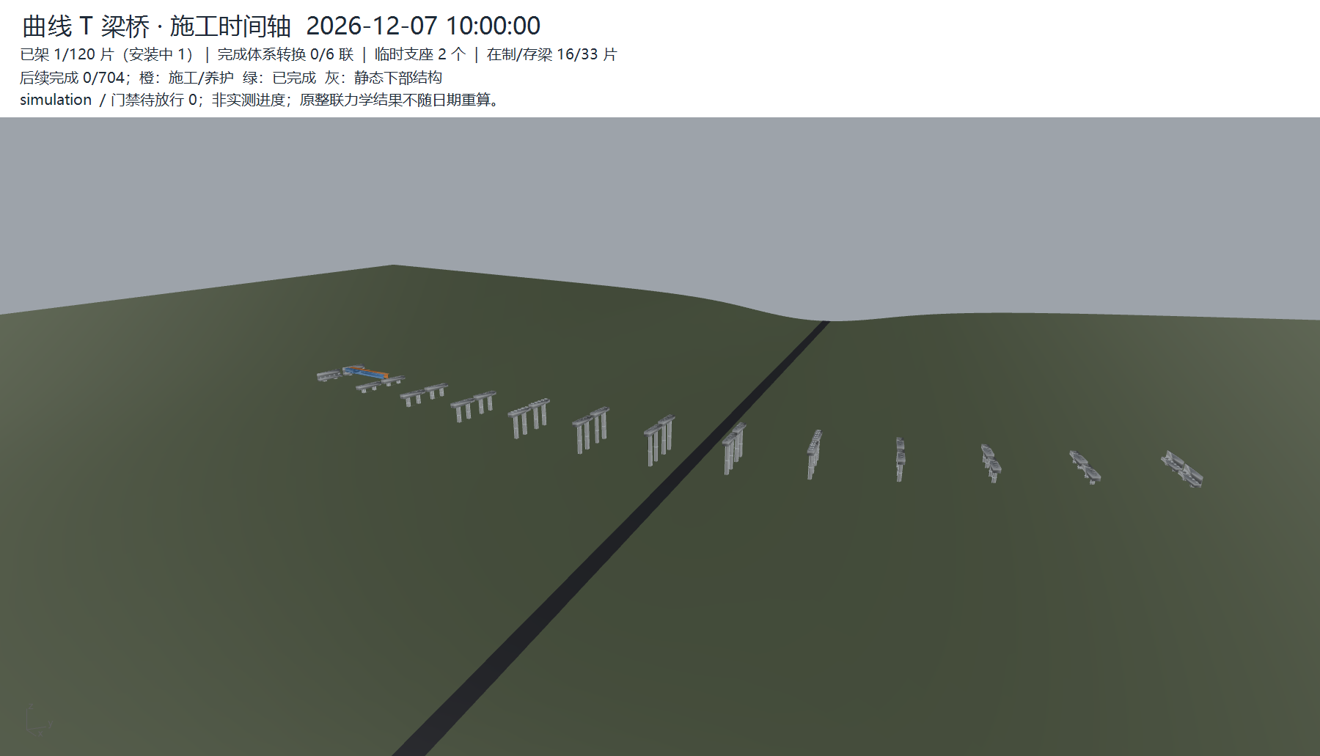
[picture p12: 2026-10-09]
model/replay/bridge_2026-12-07_1000.png

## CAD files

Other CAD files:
model/bridge_bim.3dm
model/project_replay/bridge_2027-07-01_1000.3dm
model/project_replay/bridge_2028-07-01_1000.3dm
model/replay/bridge_2026-12-06.3dm
model/replay/bridge_2026-12-07_0800.3dm
model/replay/bridge_2026-12-07_1000.3dm
model/replay/bridge_2026-12-21.3dm
model/replay/bridge_2027-02-02.3dm
model/replay/bridge_2027-02-20_1600_M1_L-U2-G3.3dm
model/replay/bridge_2027-02-20_1600_M2_L-U2-G3.3dm
model/replay/bridge_2027-02-20_1600_Mc_L-U2-G3.3dm
model/replay/qa/bridge_2027-01-26_0000.3dm

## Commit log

2026-09-23 Model a curved precast T-girder bridge from its alignment up
    A fictional 1110 m route (tangent, clothoid, R=700 arc, clothoid, tangent;
    parabolic crest; superelevation) carries a 12x30 m bridge in three continuous
    units, left and right decks: 990 elements in bridge/, stdlib only (Rhino 8's
    CPython 3.9 imports the same code).
    - Structural system: expansion ends at abutments and transition piers,
    continuity ends on temporary supports with one permanent bearing per
    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
    [alignment_stations.csv, bearings.csv, conversions.csv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]
2026-09-23 Build the model in Rhino 8, cut the cross-sections from it, and render the images
    rhino/build_model.py (run by scripts/run_rhino.py) adds every element as a
    named Rhino object carrying its BIM data as UserText, girders on one layer
    per precast length, and writes model/bridge_bim.3dm plus seven images:
    hero view, a continuity pier before and after system conversion, four 4D
    snapshots, the precast yard on its peak storage day, a longitudinal profile
    with the standard data table, a girder-length layout, and two cross-sections
    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
    [bridge_bim.3dm]
2026-09-23 Cross-check the artifacts, recompute every README number, and add a tamper drill and CI
    - tests/test_artifacts.py reads the committed .3dm back with rhino3dm (one
    object per element, every UserText value, bounding boxes, closed meshes,
    no local paths) and the IFC with ifcopenshell: schema validation, classes
    and predefined types, the spatial tree, per-element volume and position
    from the OpenCascade geometry engine, the alignment evaluated by the IFC
    geometry kernel against our own integration, stationing referents and
    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
2026-09-23 Analyse the superstructure in construction stages and write the results back into the BIM
    bridge/structure.py (standard library only, so Rhino's Python 3.9 runs it)
    builds one beam model per girder line from the model's own elements: two
    decks x three units x five girder positions = 30 four-span lines of precast
    girders joined by cast-in-place continuity segments.
    - Sections by polygon integration (precast, composite, solid joint block);
    lateral distribution by the modified eccentric-pressure method at midspan
    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
    [bearing_reactions.csv, bearings.csv, bridge_bim.3dm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]
2026-09-23 Follow the textbook and the literature where the online review found gaps
    A review against online sources (the qlgc.readthedocs.io transcription of the
    bridge-engineering textbook, the JTG 3362 / D60 transcriptions, Wang et al.,
    Journal of Highway and Transportation Research and Development 2018(5), and a
    manufacturer's JT/T 4 bearing table) found three places where the model
    diverged from them:
    - Lateral distribution in the continuous stage now uses the textbook's
    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
    [bearing_reactions.csv, bearings.csv, bridge_bim.3dm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]
2026-09-24 Check bearing movements and the narrow-bridge criterion; slide the expansion ends
    Two items the online review had left open are now computed rather than listed
    as not done.
    Bearing movements (JTG 3362-2018 8.7.3-8.7.5, movements by the 8.8.2 method):
    - Each deck unit's fixed point is the plan centroid of the laminated bearings'
    shear stiffness (sliding bearings excluded, piers rigid); every bearing moves
    by its plan distance times the strain. Temperature uses the D60 effective
    temperatures (warm zone, set at 10-20 C, both assumptions); shrinkage and
    creep follow Appendix C with the bearing's age taken from the yard and
    erection schedule (18 d at erection, 19 d at the continuity po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
    [bearing_design.csv, bearing_reactions.csv, bearing_sensitivity.csv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]
2026-09-24 Show the girder lengths in the dark cells of the length chart
    Every annotation had a text mask filled with the viewport colour (white), so each
    cell of the girder-length chart carried a white box behind its number, and in the
    four dark colours the white numbers vanished into it. text() now takes
    mask=False for text written on a fill; everything else keeps the mask that
    hides lines under labels. Only docs/img/length_specs.png is re-committed; the
    other renders differed only by sampling noise.
    A standard-library PNG reader in the artifact tests looks for white regions
    enclosed by colour: the old chart has 120 of them above 200 px, one per cell,
    the new one none (glyph strokes stay under 100 p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
    [bridge_bim.3dm]
2026-10-09 Complete Rhino construction timeline and stage result delivery
    [bridge_2026-12-06.3dm, bridge_2026-12-07_0800.3dm, bridge_2026-12-07_1000.3dm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]
2026-10-09 Compare stage moment curves with verified normwise tolerance
2026-10-09 Distinguish clearance boundaries and clarify fixed construction crews
    [bridge_2026-12-06.3dm, bridge_2026-12-07_0800.3dm, bridge_2026-12-07_1000.3dm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]
2026-10-09 Configure construction crews calendars and approval-gated Rhino IFC replay
    [bridge_2026-12-06.3dm, bridge_2026-12-07_0800.3dm, bridge_2026-12-07_1000.3dm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]
2026-10-09 Verify construction scheduling resources and source geometry (#4)
    [bridge_2026-12-06.3dm, bridge_2026-12-07_0800.3dm, bridge_2026-12-07_1000.3dm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]
